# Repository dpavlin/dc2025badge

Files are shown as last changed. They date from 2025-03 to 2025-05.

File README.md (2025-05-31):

# DORS/CLUC Conference badge 2025

Conference page with badge instructions: [https://www.dorscluc.org/badge](https://www.dorscluc.org/badge/)

Build log: [https://hyperglitch.com/articles/dc2025-badge](https://hyperglitch.com/articles/dc2025-badge)

- `/hardware` - KiCad files for the badge
- `/firmware` - firmware for the badge
- `/3D` - 3D models for the stand, tag and programming jig
- `/notification_handler.py` - Python script for displaying the notifications and clock on the badge (in notifier mode)

----------------------------------------

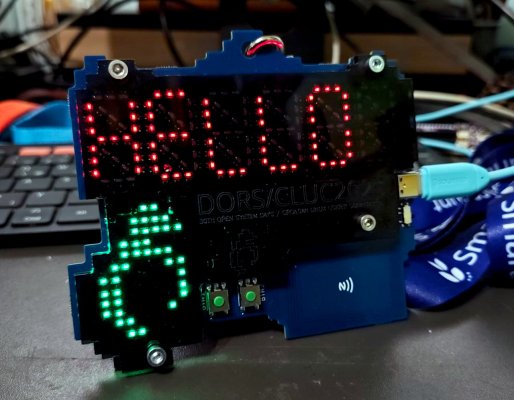
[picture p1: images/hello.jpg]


This year’s badge has a number of functionalities, to be used both during and after the conference. During the conference the display can show your name (or any other text) and you also use it for quests. After the conference it can be used as a handy desktop notifier or a clock. And, of course, there’s a game available on it (not really Doom but it’s fast paced and action packed).

The badge contains a six character 9-segment display, logo shaped LED matrix, a NFC reader/writer, two buttons and a USB connection.

## How to set my own text?

The badge has six character alphanumeric display. It can show messages of up to 30 characters.

To set your custom text, hold the BTN1 for about three to five seconds until the badge switches to configuration mode. In that mode the BTN1 will move the cursor position while BTN2 will change the character under the cursor (hold it for fast character listing). To delete a character, select a space symbol (after number 9). To save the text hold the BTN1 again for three to five seconds until OK appears on screen.

## Quests? You said quests?

Yes! One is treasure hunt and another is badge hunt.

On the conference site there are nine hidden tags and your quest is to “collect” them all (tap them with your badge, please don’t physically take them). Each hidden tag will light up part of the logo on the badge. The first person who gets all of them will get a small reward.

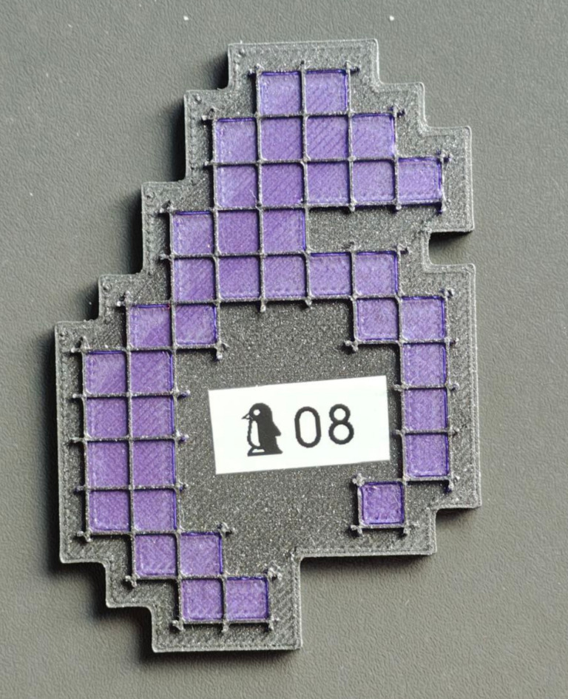
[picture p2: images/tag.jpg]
An example of a hidden tag


Just like the last year’s badge which motivated attendants to interact with each other, this year’s badge also has an “interaction counter”. Put the antennas on two badges next to each other for a couple of seconds (it’s best to hold them both upwards and put antennas one over another so both screens could be seen) until both of them show the “NEW BADGE FOUND” text and they will exchange their details, incrementing the badge counter. NOTE: due to the power saving feature this might need to be repeated multiple times.

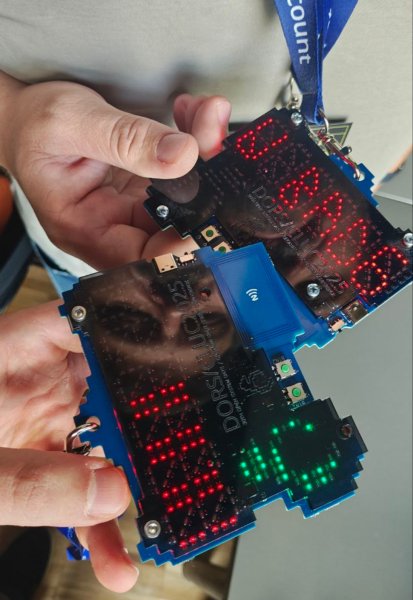
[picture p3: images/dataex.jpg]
How to hold badges for data exchange


To check the current status of both quests press the BTN2 once or twice.

Note: in order to preserve the battery life, the NFC reader is in power save mode and it will activate when it detects a moving metal object nearby. Because of that sometimes it will be necessary to try the action (tapping the hidden tag or another badge) a couple of times.

## There are other modes?

I’m glad you asked. Yes, there are other modes on the badge:

- Conference mode scrolling text with quests)
- Clock (not really precise, needs configuration)
- Notifier (“passthrough” mode allowing you to set the screen over USB so it can be used as a desktop notifier)
- Game (a game!)
- Test (hardware test used during production)

To change the mode press and hold both buttons while powering on the badge. After a couple of seconds MODE will appear on screen. Use buttons to select the mode you like to try and press and hold both buttons for three to five seconds to confirm the selection.

## Configuration

When the badge is not in the notifier mode, some settings can be configured using the configuration menu available over USB connection. Connect the badge to computer (it probably won’t work on smartphone) and a new serial port will appear (/dev/ttyACM* on Linux, COM* on Windows). Connect to it either using some terminal program (miniterm, putty, screen, …) or even a web client such as the one available at https://www.anticyclone-systems.co.uk/aslwebterm.php (a Chromium based browser needs to be used as Firefox doesn’t support WebSerial). Make sure that Enter is set as CR+LF, click Connect and select your badge. Press Enter to redraw the menu. In case the Enter doesn’t work, try Ctrl+J.

## Notifier mode

When in notifier mode the serial terminal isn’t used for configuration but for the control. Each command must end ith a newline. Here are the commands:

- `S<some text>` will display that text on screen (for example “`Sshow this`”)
- `G<char_idx><segment_idx><1|0>` will control a specified character segment. `<char_idx>` is character index (0-5), `<segment_idx>` is the index of the segment (0-8) and `1|0` controls whether to turn the segment on or off. For example “`G161`” will turn on the middle horizontal segment on second character.
- `L<led_idx><1|0>` will turn the specified LED in the logo on or off. `<led_idx>` is in the range 00-39 (with leading zero). For example “`L021`” will turn on the led with index 2.
- `C` will clear the screen and LED matrix.
- `B<brightness>` will set the brightness where the `<brightness>` is in the rangge 00-99 (with leading zero). For example “`B05`” will set the brightness to 5%.

## License

ST middlewares and libraries are licensed under ST SLA0044 license. Shell menu is licensed under GPLv3. The rest of the code is licensed under MIT license.

The badge is designed by Igor Brkić from [https://hyperglitch.com](https://hyperglitch.com).

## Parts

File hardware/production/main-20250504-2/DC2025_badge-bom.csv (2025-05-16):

Comment | Designator | Footprint | LCSC
TVS3V | D1,D207,D208,D209,D210,D211,D213,D214 | Diode_SMD:D_SOD-323 | C502526
1uF | C4,C10,C23,C41,C42,C43,C44 | Capacitor_SMD:C_0603_1608Metric | C59302
100k | R1,R3,R4,R8,R11,R178 | Resistor_SMD:R_0402_1005Metric | C25741
SMF5.0A | D203,D204,D205,D206 | Diode_SMD:D_SMF | C19077497
Cover nut | H3,H4,H5,H6 | SMTSO:SMTSO3025CTJ | C2916365
100nF | C1,C5,C6,C7,C9,C11,C15,C16,C17,C18,C19,C20,C21,C22,C29,C45 | Capacitor_SMD:C_0402_1005Metric | C307331
SKHMQLE010 | S2,S3 | SW_SKHMQLE010:SW_SKHMQLE010 | C139767
22nF | C3 | Capacitor_SMD:C_0402_1005Metric | C1532
USB_C_Receptacle_USB2.0_16P | J1 | Connector_USB:USB_C_Receptacle_GCT_USB4105-xx-A_16P_TopMnt_Horizontal | C165948
TPS3808DBV | U1 | Package_TO_SOT_SMD:SOT-23-6 | C19653
AO3401A | Q1 | Package_TO_SOT_SMD:SOT-23 | C15127
5.1k | R6,R7,R9,R10 | Resistor_SMD:R_0402_1005Metric | C25905
SSSS811101 | S1 | SW_SSSS811101:SW_SSSS811101 | C109335
STM32L073RBT6 | U2 | Package_QFP:LQFP-64_10x10mm_P0.5mm | C2917159
XC6206P332MR | U5,U6 | Package_TO_SOT_SMD:SOT-23-3 | C5446
10k | R5,R177,R179,R180,R181,R182,R183 | Resistor_SMD:R_0402_1005Metric | C25744
MBR0530 | D212 | Diode_SMD:D_SOD-123 | C475718
10uF | C2,C8,C28 | Capacitor_SMD:C_0603_1608Metric | C237435
47R | R12,R13,R14,R15,R16,R17,R18,R19,R20,R21,R22,R23,R24,R25,R26,R27,R28,R29,R30,R31,R32,R33,R34,R35,R36,R37,R38,R39,R40,R41,R42,R43,R44,R45,R46,R47,R48,R49,R50,R51,R52,R53,R54,R55,R56,R57,R58,R59,R60,R61,R62,R63,R64,R65,R66,R67,R68,R69,R70,R71,R72,R73,R74,R75,R76,R77,R78,R79,R80,R81,R82,R83,R84,R85,R86,R87,R88,R89,R90,R91,R92,R93,R94,R95,R96,R97,R98,R99,R100,R101,R102,R103,R104,R105,R106,R107,R108,R109,R110,R111 | Resistor_SMD:R_0402_1005Metric | C25118
47R | R112,R113,R114,R115,R116,R117,R118,R119,R120,R121,R122,R123,R124,R125,R126,R127,R128,R129,R130,R131,R132,R133,R134,R135,R136,R137,R138,R139,R140,R141,R142,R143,R144,R145,R146,R147,R148,R149,R150,R151,R152,R153,R154,R155,R156,R157,R158,R159,R160,R161,R162,R163,R164,R165,R166,R167,R168,R169,R170,R171,R172,R173 | Resistor_SMD:R_0402_1005Metric | C25118
RED | D41,D42,D43,D44,D45,D46,D47,D48,D49,D50,D51,D52,D53,D54,D55,D56,D57,D58,D59,D60,D61,D62,D63,D64,D65,D66,D67,D68,D69,D70,D71,D72,D73,D74,D75,D76,D77,D78,D79,D80,D81,D82,D83,D84,D85,D86,D87,D88,D89,D90,D91,D92,D93,D94,D95,D96,D97,D98,D99,D100,D101,D102,D103,D104,D105,D106,D107,D108,D109,D110,D111,D112,D113,D114,D115,D116,D117,D118,D119,D120,D121,D122,D123,D124,D125,D126,D127,D128,D129,D130,D131,D132,D133,D134,D135,D136,D137,D138,D139,D140 | LED_SMD:LED_0603_1608Metric | C965799
RED | D141,D142,D143,D144,D145,D146,D147,D148,D149,D150,D151,D152,D153,D154,D155,D156,D157,D158,D159,D160,D161,D162,D163,D164,D165,D166,D167,D168,D169,D170,D171,D172,D173,D174,D175,D176,D177,D178,D179,D180,D181,D182,D183,D184,D185,D186,D187,D188,D189,D190,D191,D192,D193,D194,D195,D196,D197,D198,D199,D200,D201,D202 | LED_SMD:LED_0603_1608Metric | C965799
GRN | D2,D3,D4,D5,D6,D7,D8,D9,D10,D11,D12,D13,D14,D15,D16,D17,D18,D19,D20,D21,D22,D23,D24,D25,D26,D27,D28,D29,D30,D31,D32,D33,D34,D35,D36,D37,D38,D39,D40 | LED_SMD:LED_0603_1608Metric | C965804
IS31FL3731-QF | U3 | Package_DFN_QFN:QFN-28-1EP_4x4mm_P0.4mm_EP2.3x2.3mm | C191206
2.2uF | C14,C24,C25,C26,C27,C34 | Capacitor_SMD:C_0603_1608Metric | C23630
150pF | C36,C37,C39,C40 | Capacitor_SMD:C_0402_1005Metric | C1527
ST25R3916-AQWT | U4 | Package_DFN_QFN:UFQFPN-32-1EP_5x5mm_P0.5mm_EP3.5x3.5mm | C2908147
220pF | C30,C33 | Capacitor_SMD:C_0402_1005Metric | C1530
270nH | L1,L2 | Inductor_SMD:L_0402_1005Metric_Pad0.77x0.64mm_HandSolder | C907954
2R | R175,R176 | Resistor_SMD:R_0402_1005Metric | C170397
10pF | C12,C13,C35,C38 | Capacitor_SMD:C_0402_1005Metric | C32949
680pF | C31,C32 | Capacitor_SMD:C_0402_1005Metric | C1541
27.12MHz | Y1 | Crystal:Crystal_SMD_3225-4Pin_3.2x2.5mm | C29975

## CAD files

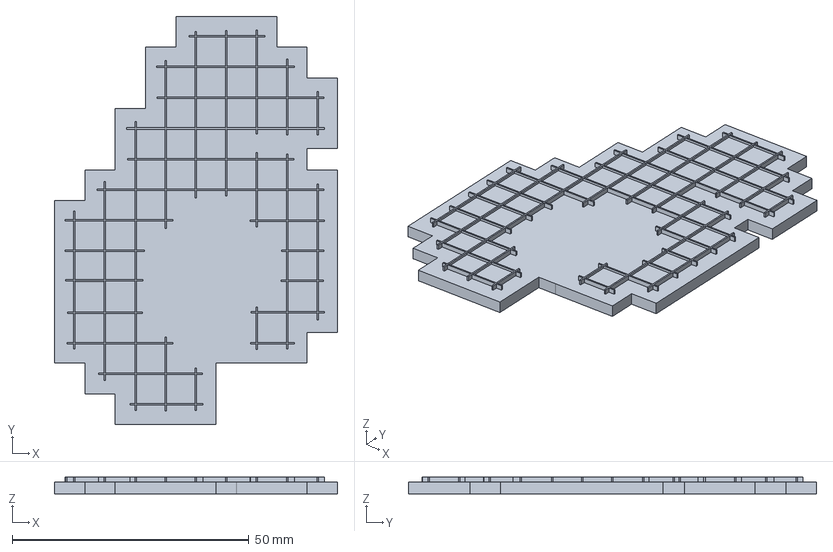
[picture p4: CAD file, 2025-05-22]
3D/treasure_hunt_tag.FCStd
59.9 x 86.2 x 3.50 mm

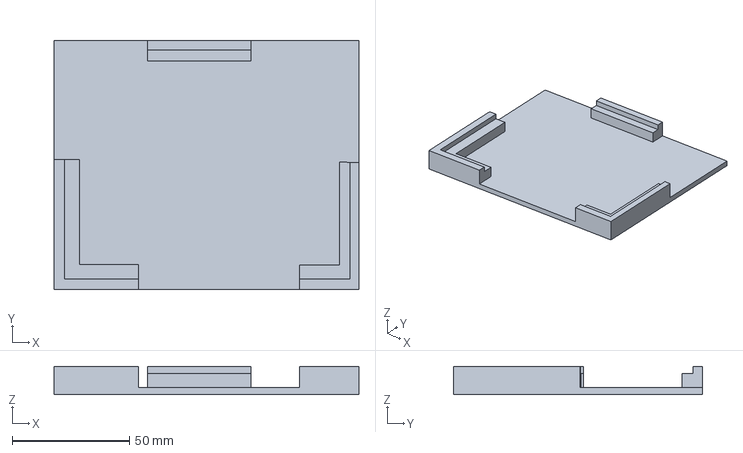
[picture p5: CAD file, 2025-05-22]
3D/programming_jig.FCStd
130.3 x 106.5 x 12.0 mm

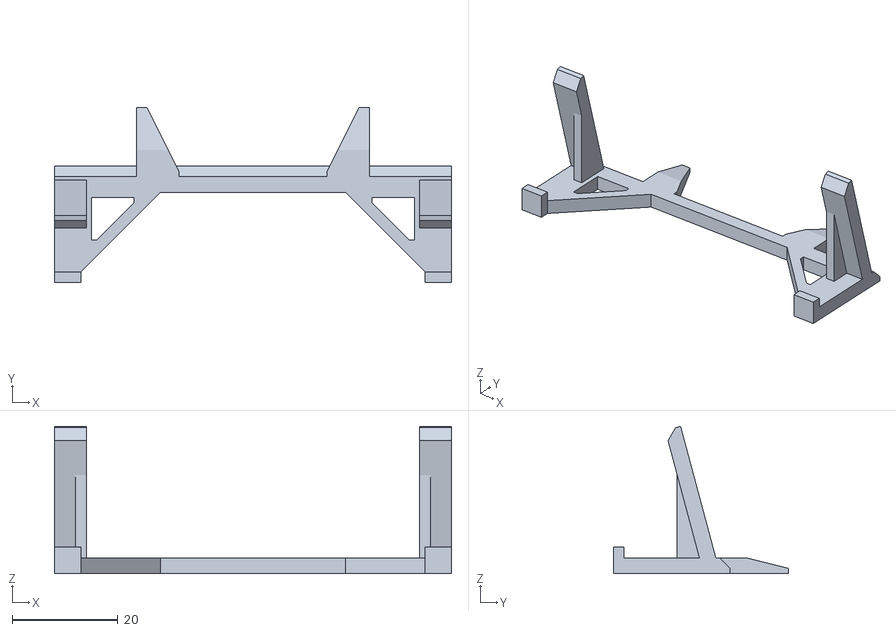
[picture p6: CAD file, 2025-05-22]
3D/badge_stand-Cut.stl
75.0 x 33.0 x 27.8

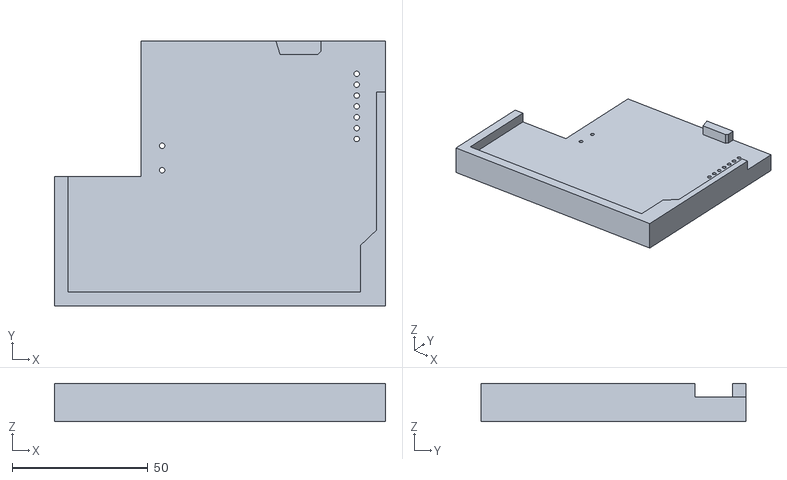
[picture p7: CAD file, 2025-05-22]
3D/programming_jig-holder.stl
121.9 x 97.6 x 14.0

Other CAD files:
3D/programming_jig-Body.stl
3D/treasure_hunt_tag-Cut.stl
3D/badge_stand.FCStd

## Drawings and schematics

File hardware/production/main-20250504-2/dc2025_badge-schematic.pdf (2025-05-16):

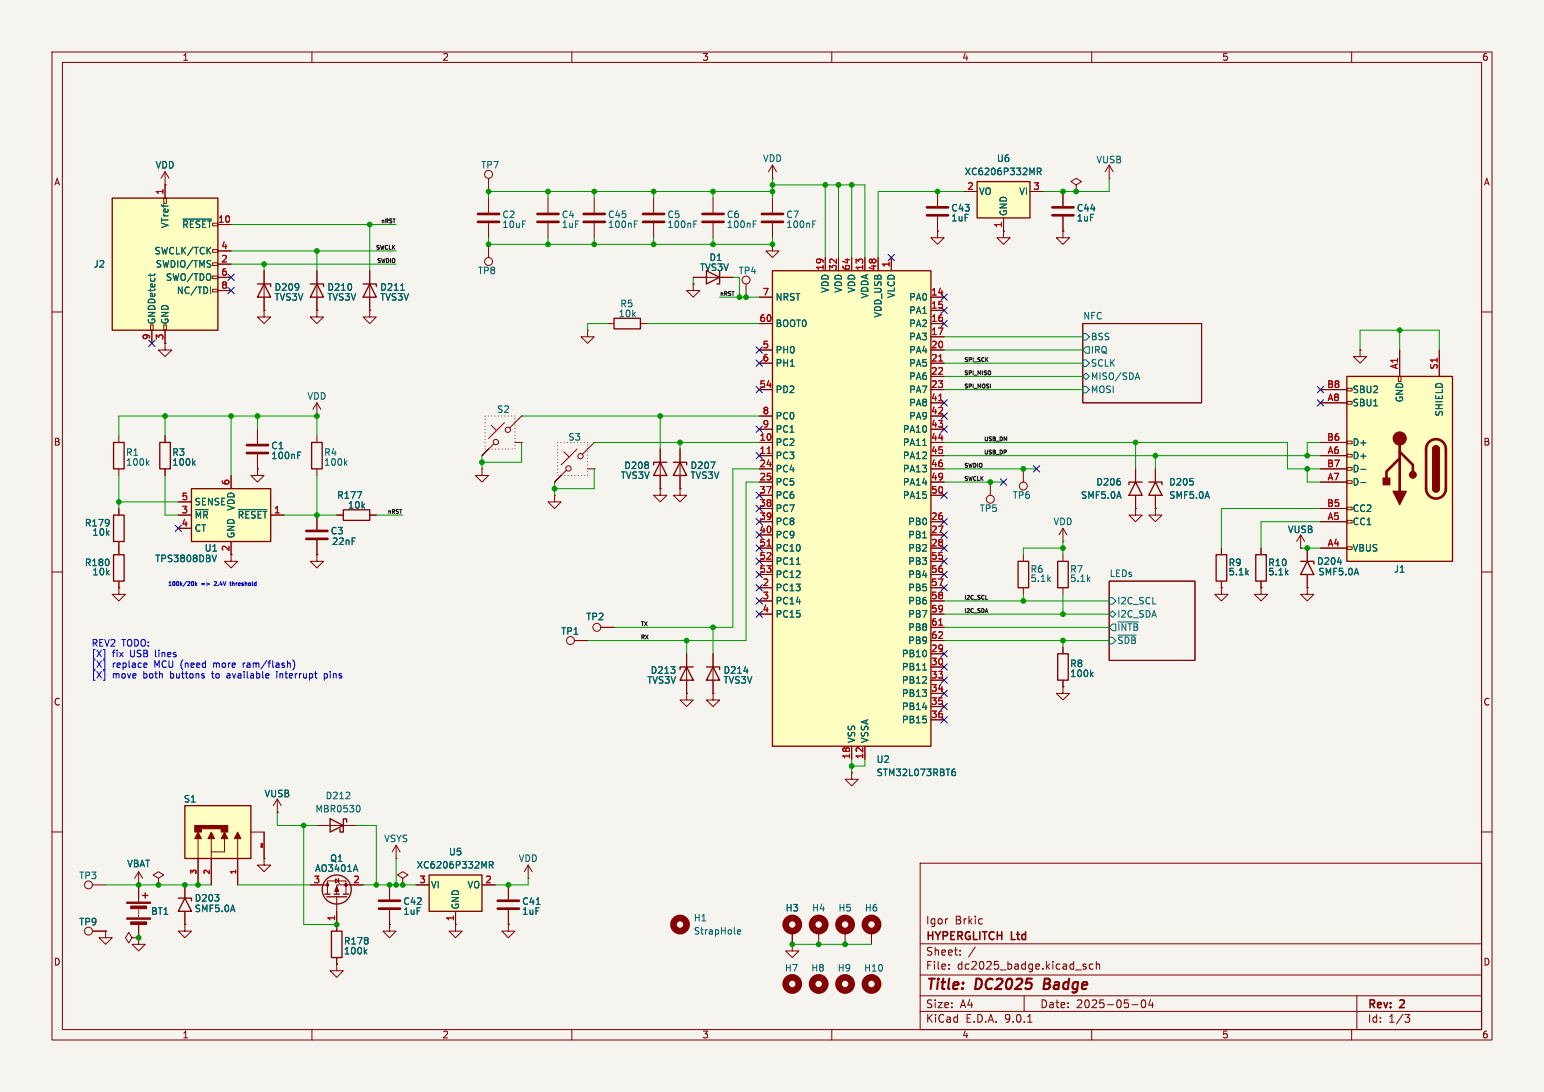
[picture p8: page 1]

3 ~{RESET}10 SWCLK/TCK 4 SWDIO/TMS 2 SWO/TDO 6 NC/TDI 8

IRQ MISO/SDA MOSI SCLK NFC
~{SDB} LEDs BSS

[X] fix USB lines
[X] replace MCU (need more ram/flash)

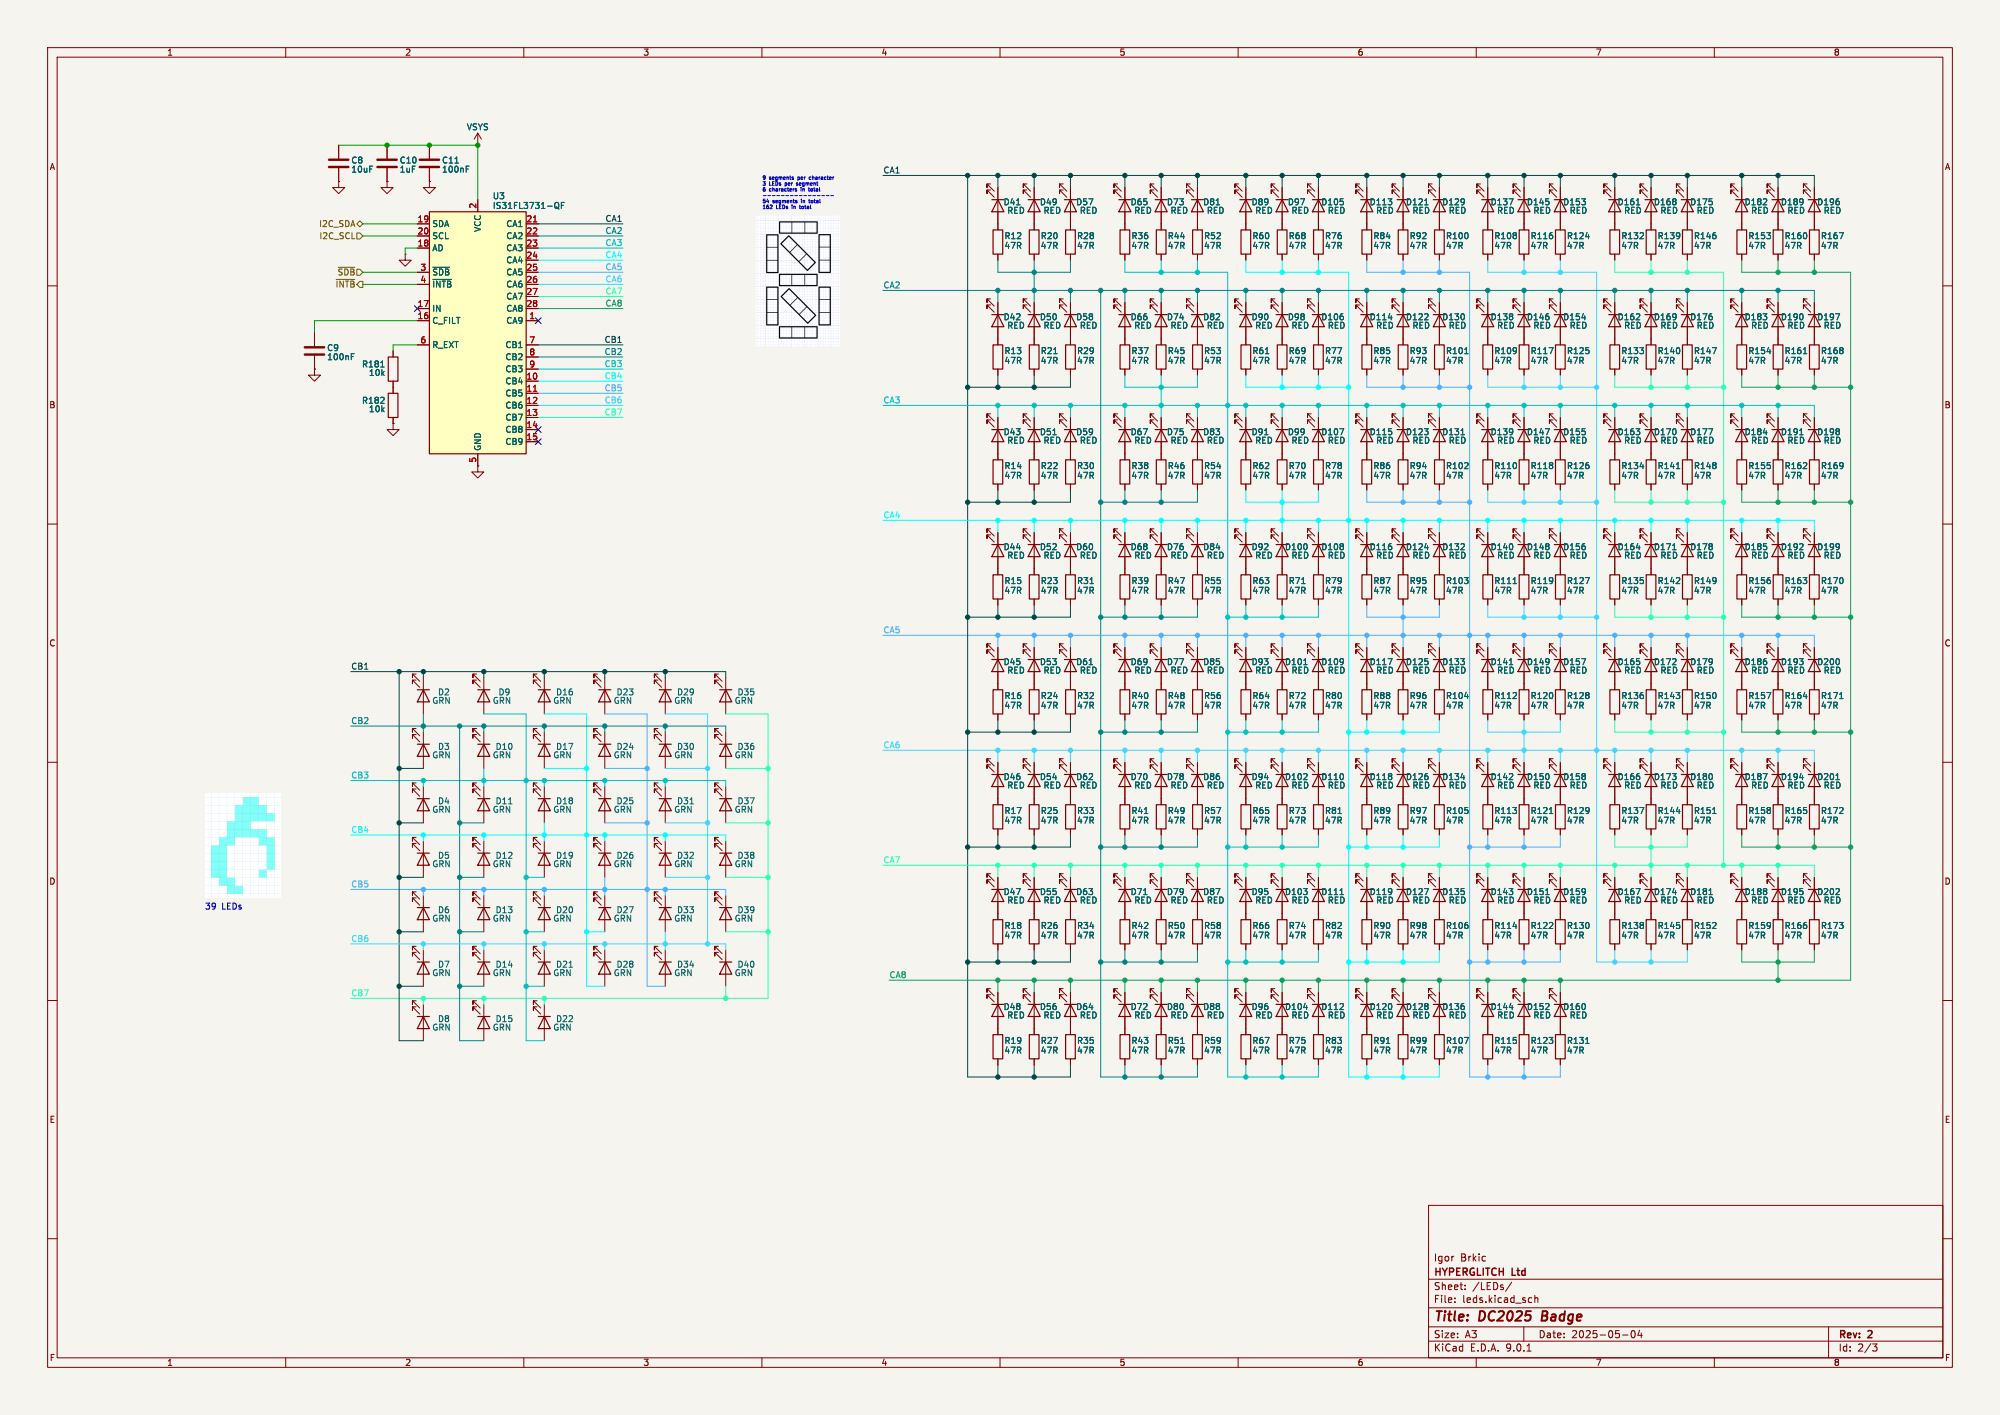
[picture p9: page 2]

IS31FL3731-QF SDA 19 SCL 20 AD 18 ~{SDB} 3 ~{INTB} 4

5 CA1 21 CA2 22 CA3 23 CA4 24 CA5 25 CA6 26 CA7 27 CA8 28 CA9 1 CB1 7 CB2 8 CB3 9 CB4 10 CB5 11 CB6 12 CB7 13 CB8 14 CB9 15 D57 RED
SDA 19 SCL 20 AD 18 ~{SDB} 3 ~{INTB} 4

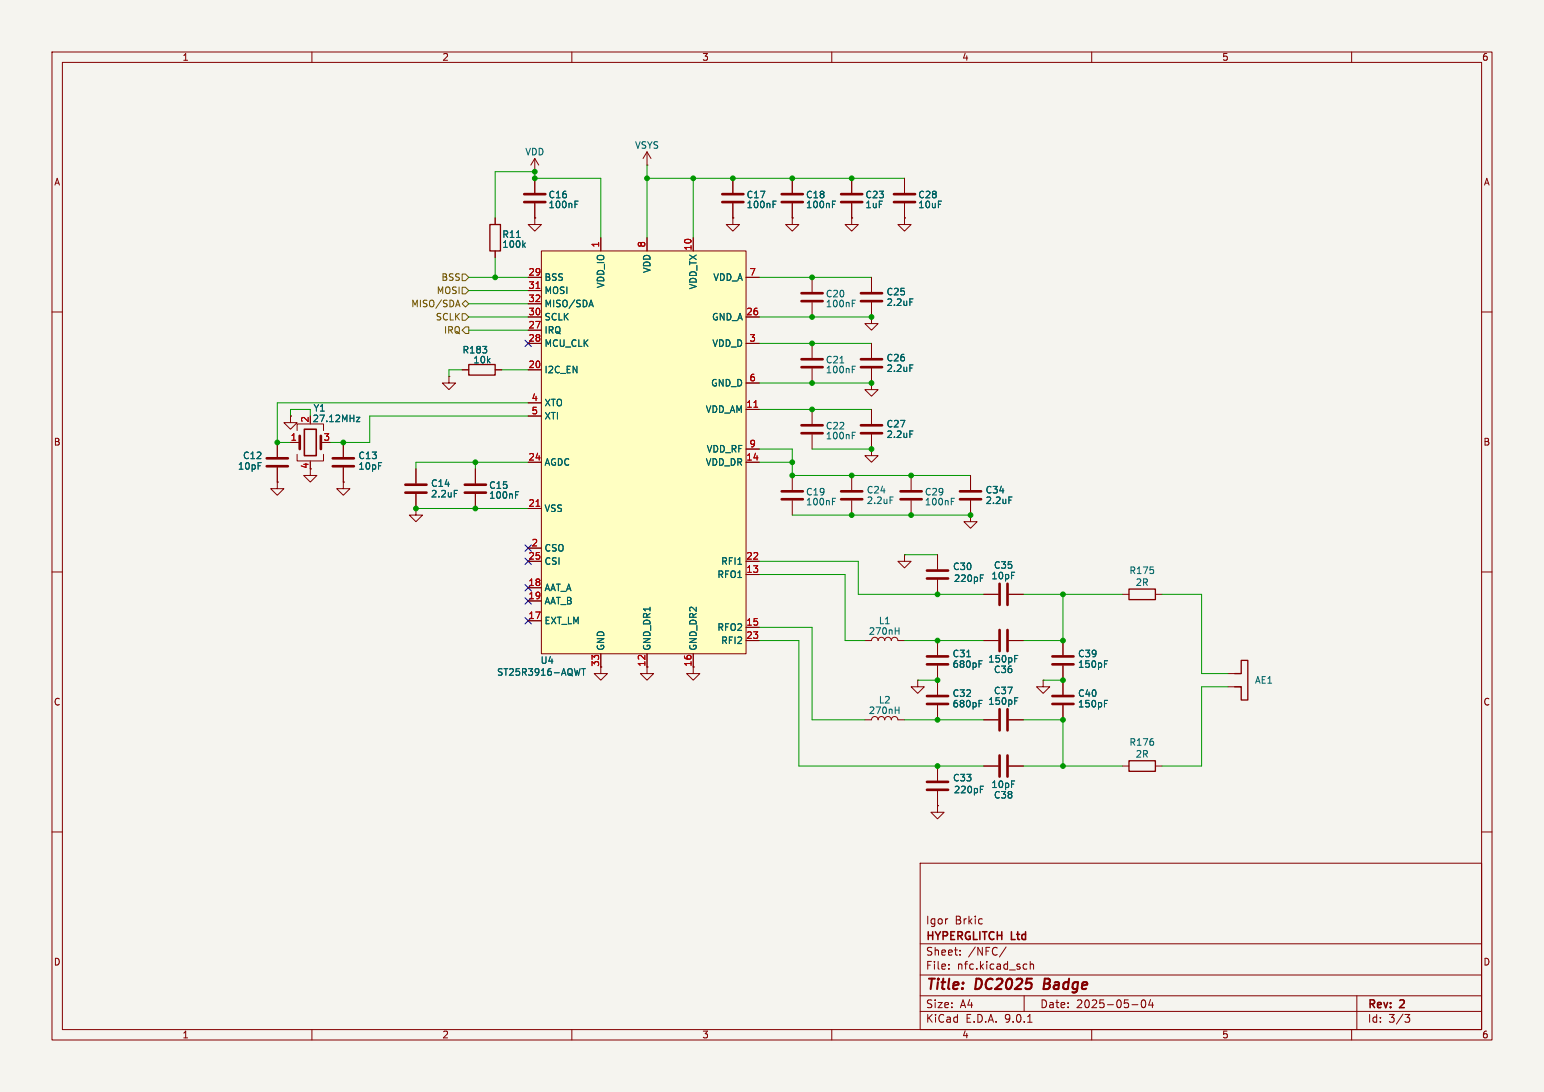
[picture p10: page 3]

BSS
IRQ MOSI MISO/SDA

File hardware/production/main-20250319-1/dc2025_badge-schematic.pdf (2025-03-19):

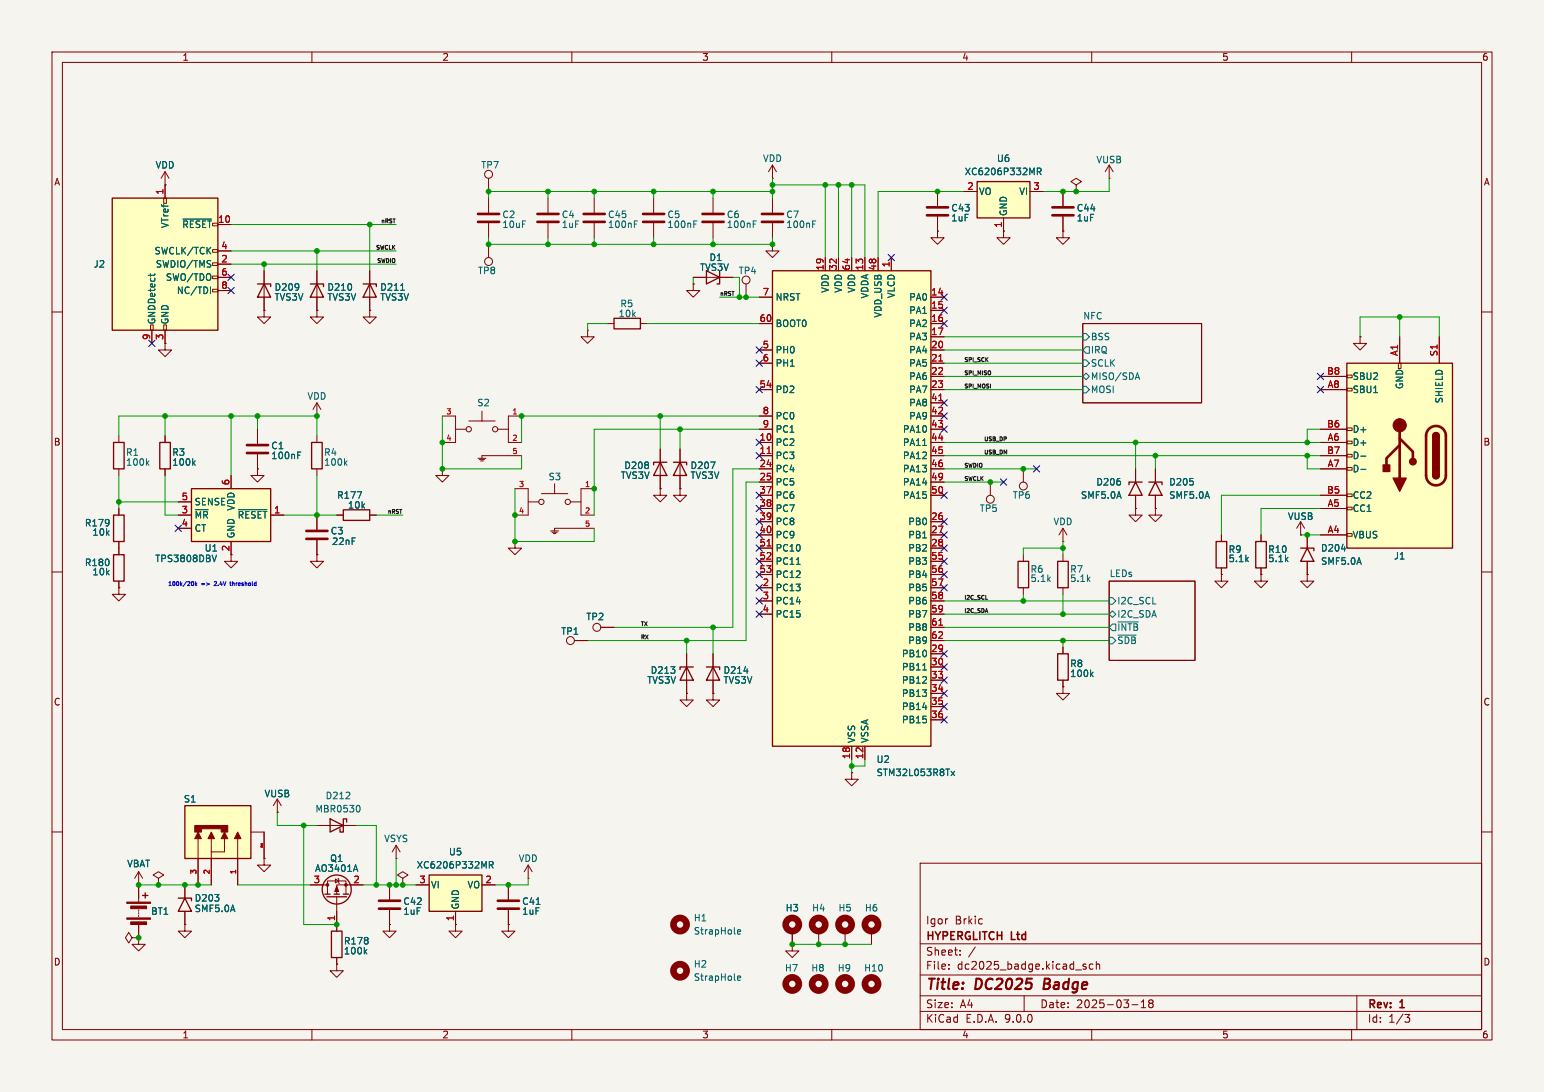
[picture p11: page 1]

3 ~{RESET}10 SWCLK/TCK 4 SWDIO/TMS 2 SWO/TDO 6 NC/TDI 8 VDD

3 ~{RESET}10 SWCLK/TCK 4 SWDIO/TMS 2 SWO/TDO 6 NC/TDI 8

IRQ MISO/SDA MOSI SCLK NFC
SPI_SCKUSB_DP USB_DM

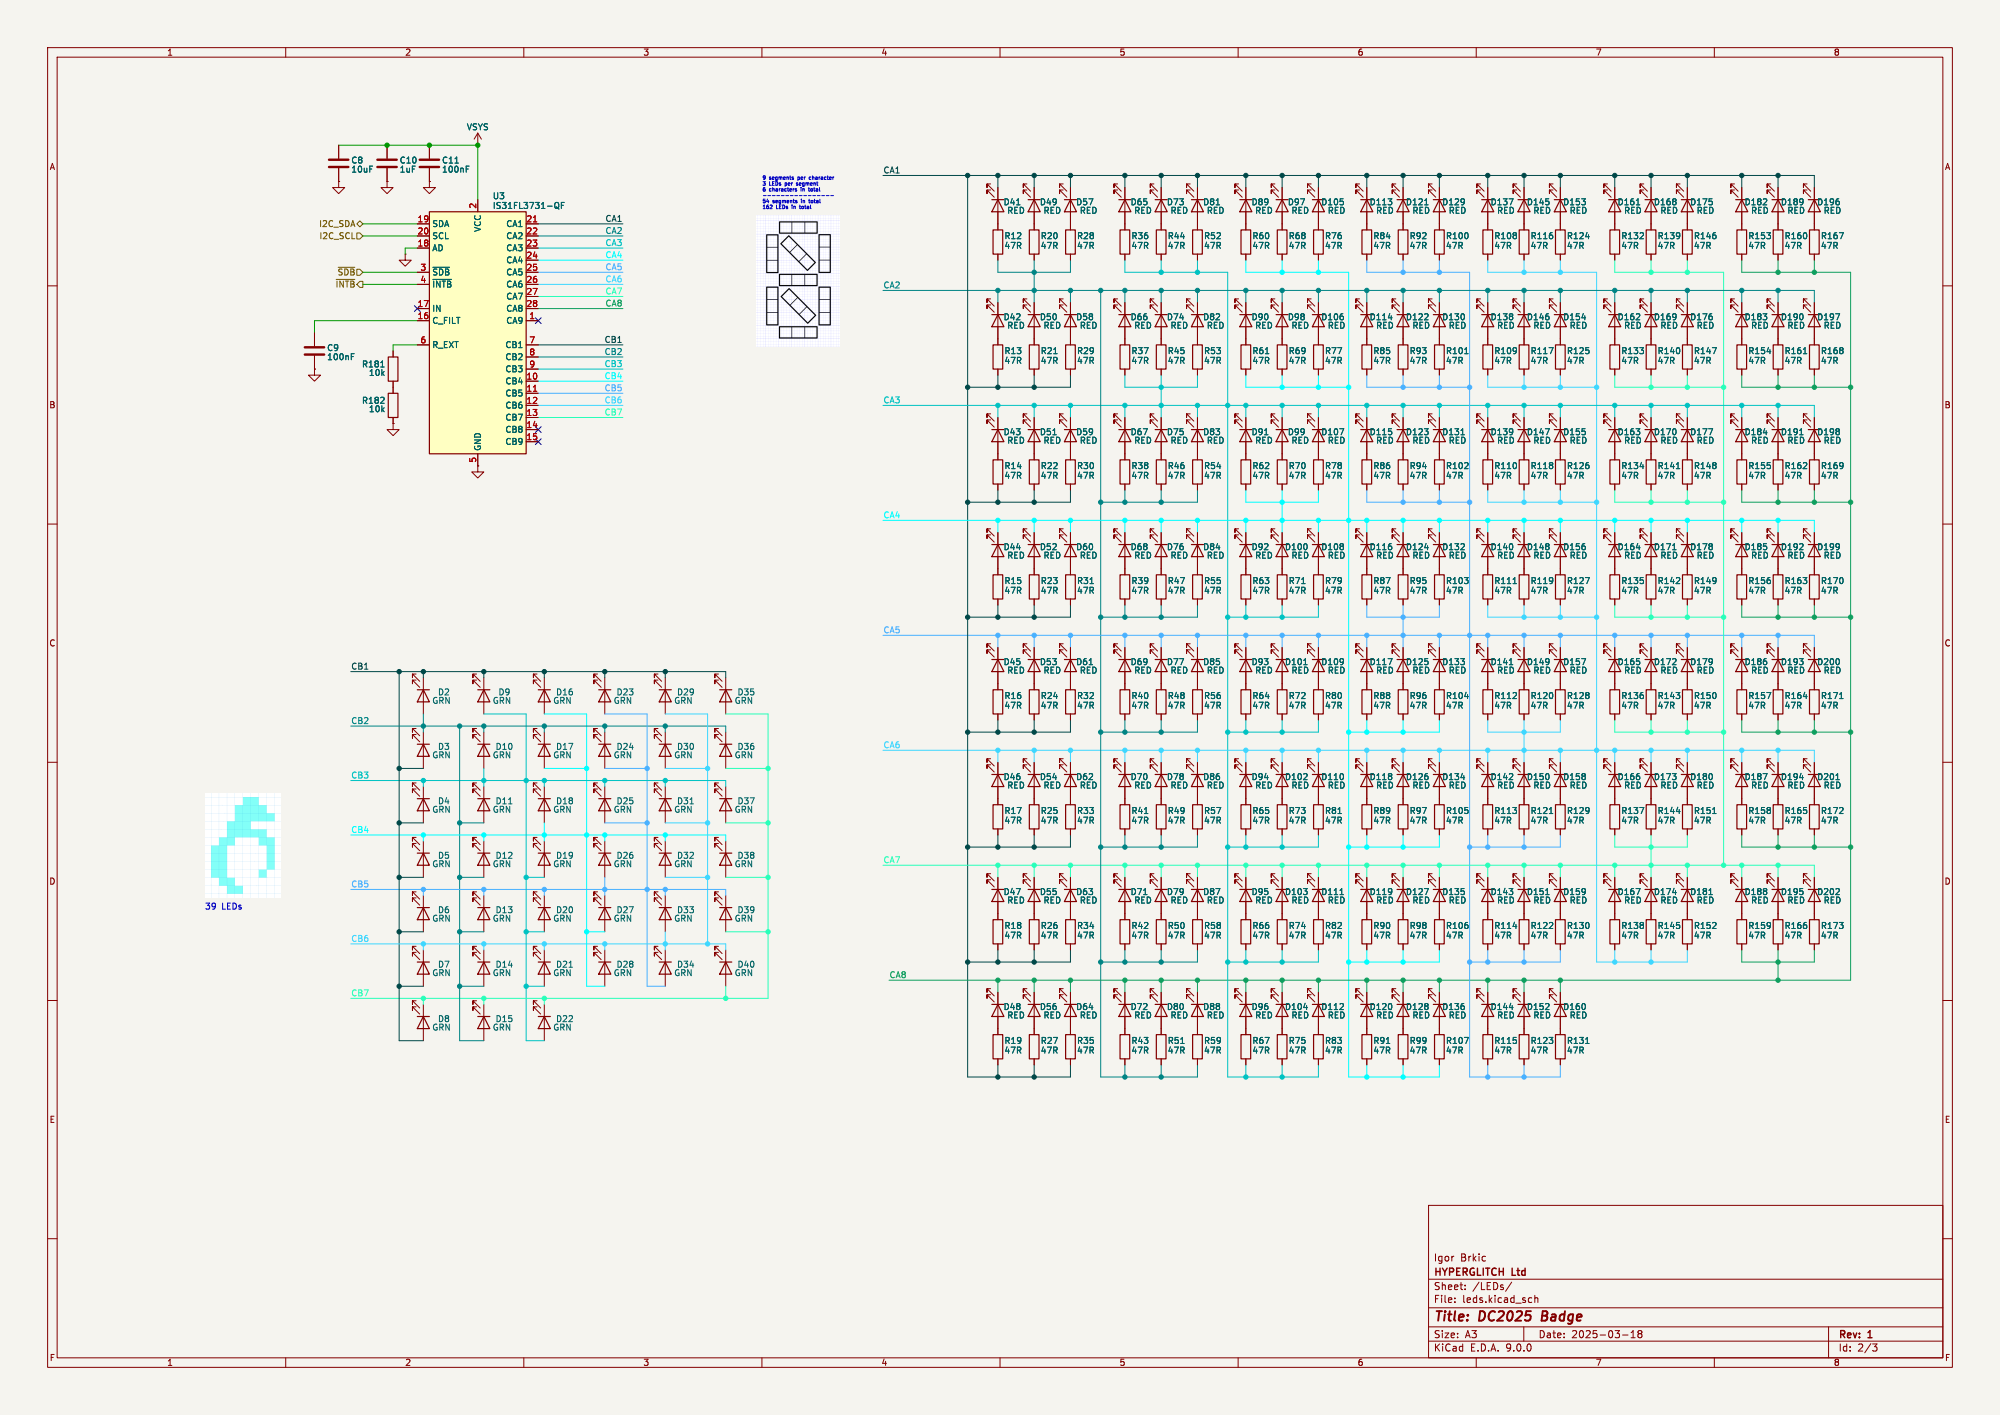
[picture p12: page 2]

IS31FL3731-QF SDA 19 SCL 20 AD 18 ~{SDB} 3 ~{INTB} 4

5 CA1 21 CA2 22 CA3 23 CA4 24 CA5 25 CA6 26 CA7 27 CA8 28 CA9 1 CB1 7 CB2 8 CB3 9 CB4 10 CB5 11 CB6 12 CB7 13 CB8 14 CB9 15 D57 RED
SDA 19 SCL 20 AD 18 ~{SDB} 3 ~{INTB} 4

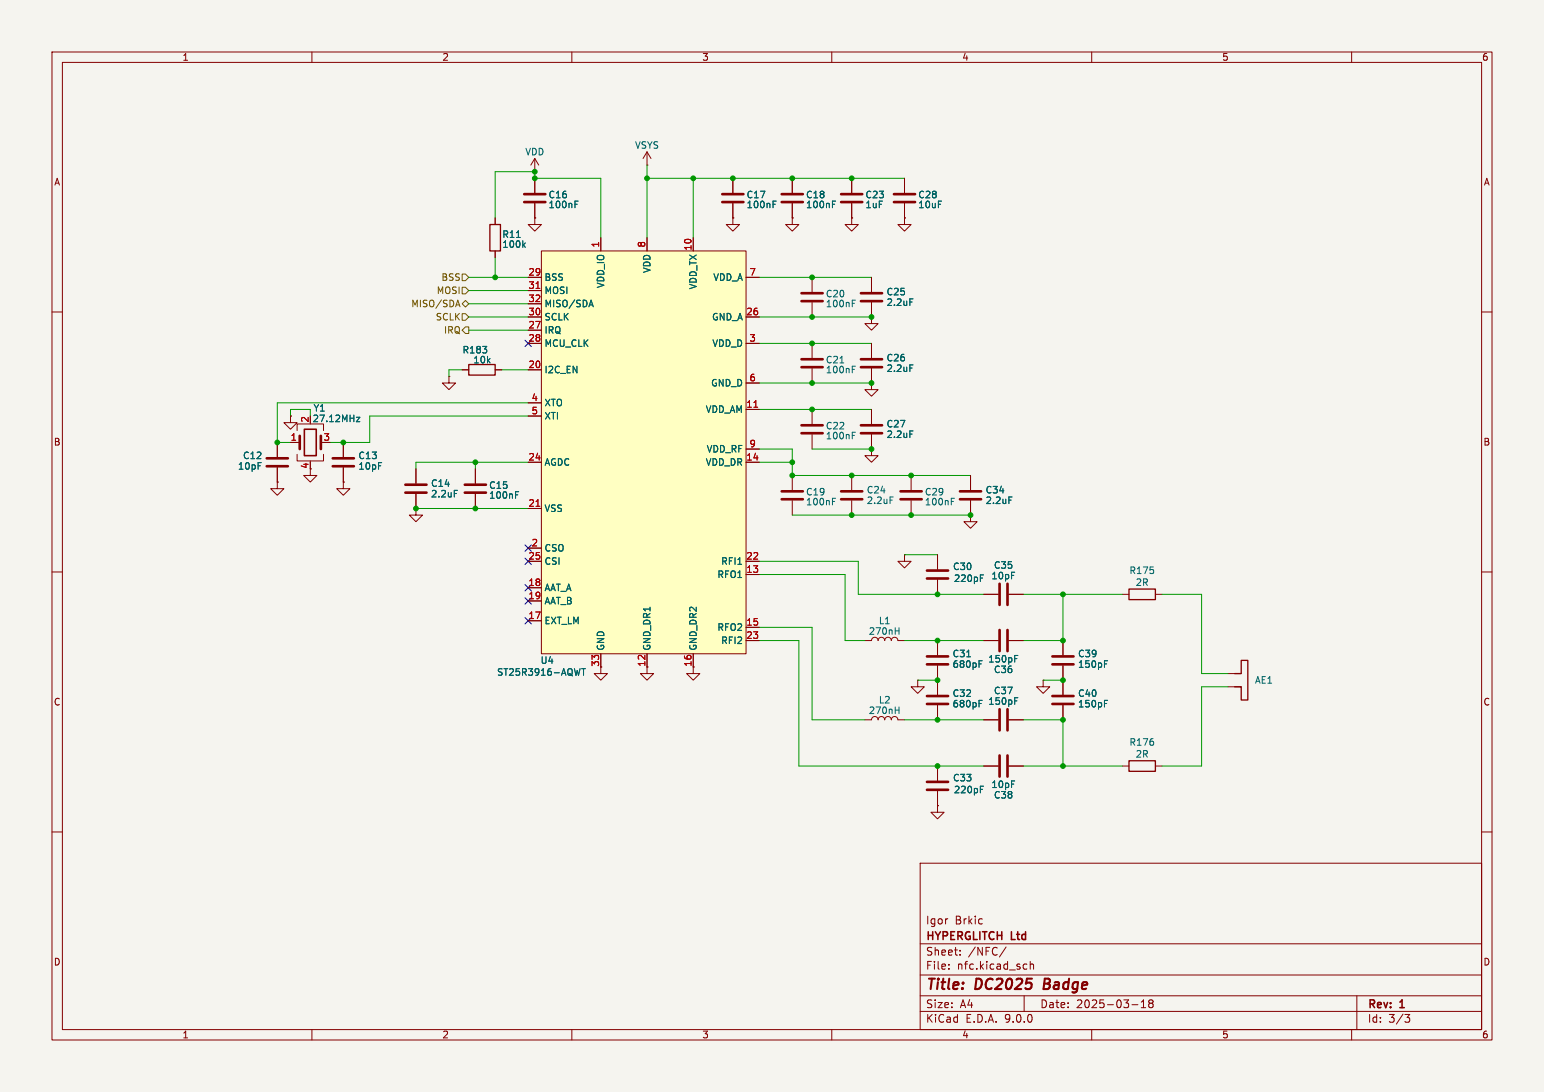
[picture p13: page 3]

BSS
IRQ MOSI MISO/SDA

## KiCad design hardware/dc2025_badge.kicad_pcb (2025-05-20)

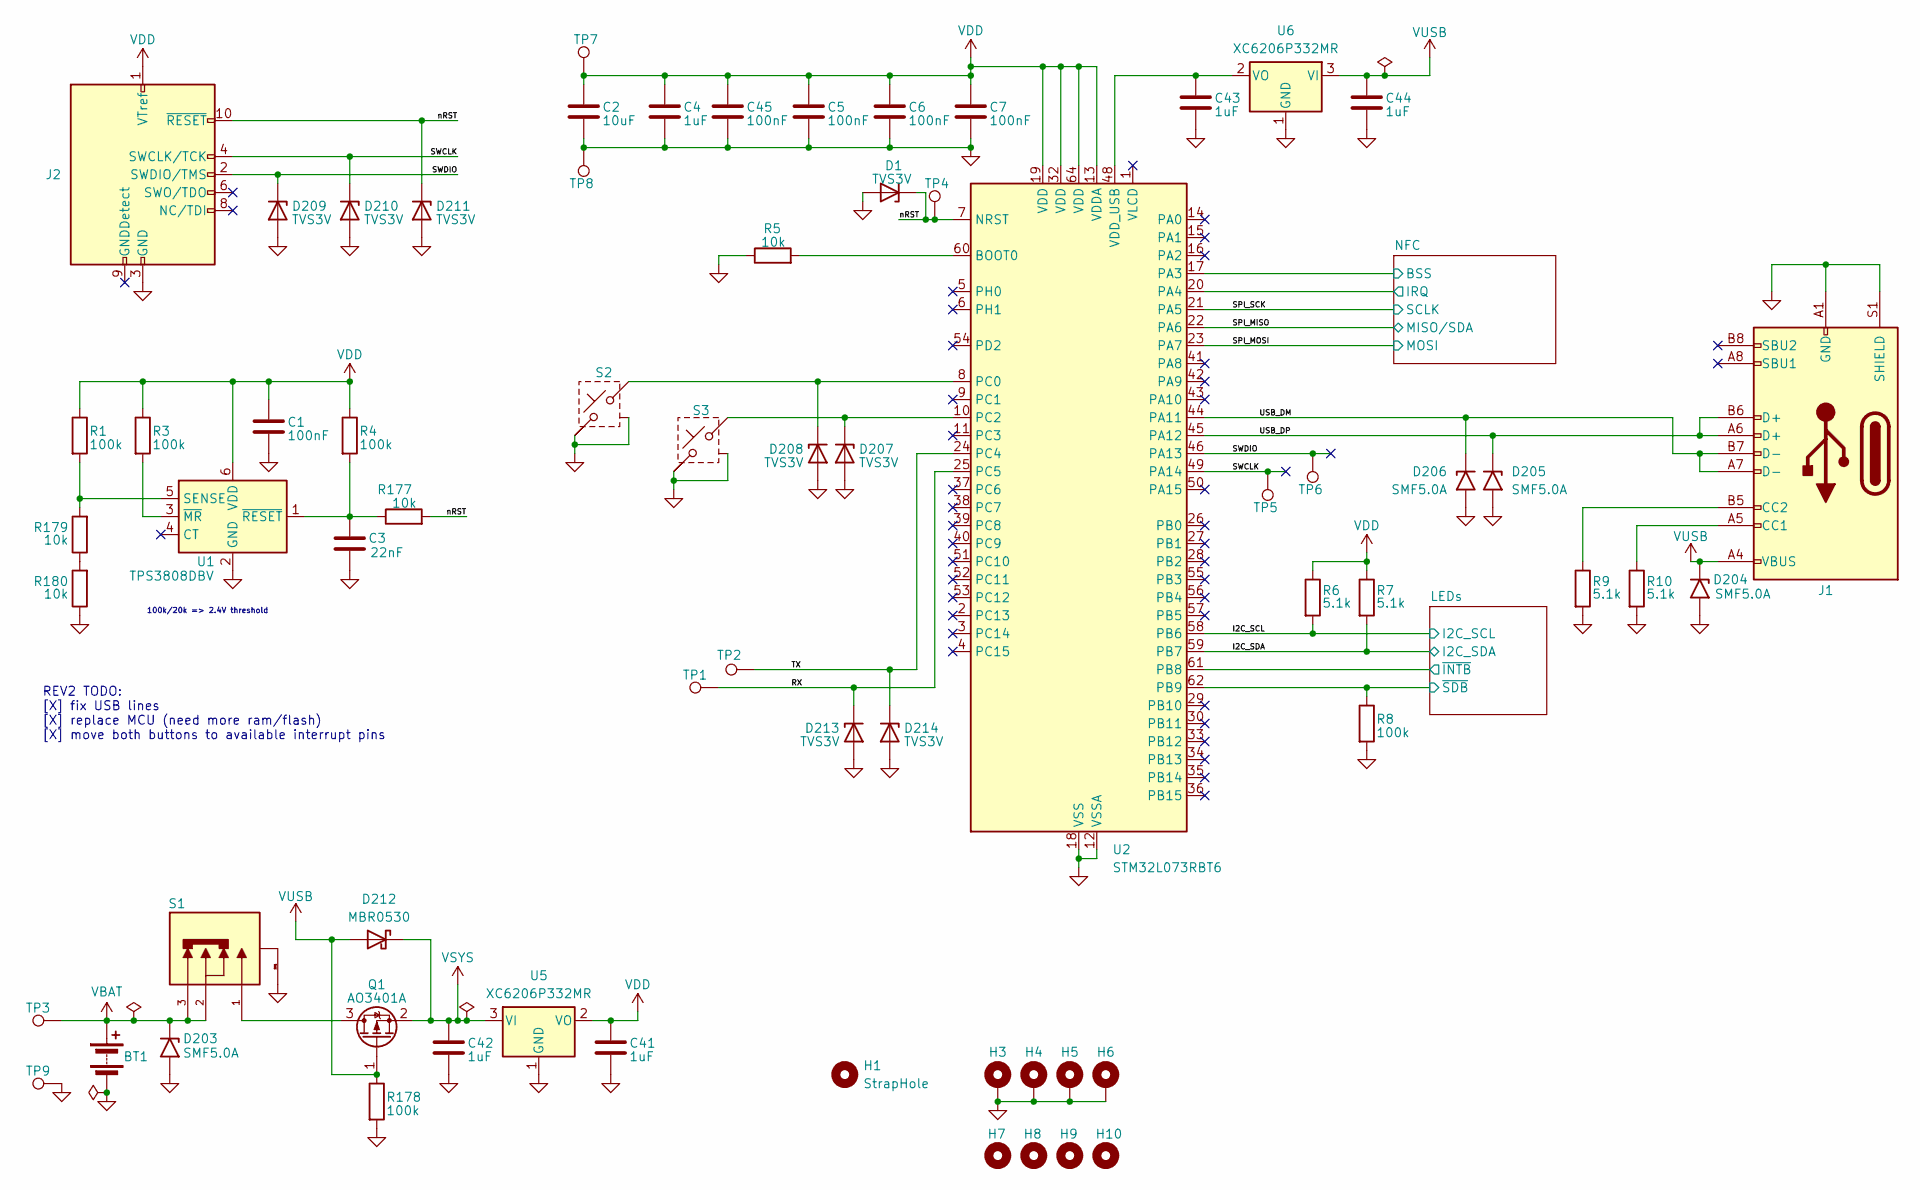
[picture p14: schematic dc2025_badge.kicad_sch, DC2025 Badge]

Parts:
BT1: Battery; keystone_2464
C1, C5, C6, C7, C45: 100nF; C_0402_1005Metric; MPN CL05B104KB54PNC; JLCPCB# C307331
C2: 10uF; C_0603_1608Metric; MPN GRM188Z71A106MA73D; JLCPCB# C237435
C3: 22nF; C_0402_1005Metric; MPN 0402B223K500NT; JLCPCB# C1532
C4, C41, C42, C43, C44: 1uF; C_0603_1608Metric; MPN 0603B105K250NT; JLCPCB# C59302
D1, D207, D208, D209, D210, D211, D213, D214: TVS3V; D_SOD-323; MPN SD03; JLCPCB# C502526
D203, D204, D205, D206: SMF5.0A; D_SMF; MPN SMF5.0A; JLCPCB# C19077497
D212: MBR0530; D_SOD-123; MPN MBR0530; JLCPCB# C475718
H1: StrapHole; MountingHole_5mm
H3, H4, H5, H6: Cover nut; SMTSO3025CTJ; MPN C2916365; JLCPCB# C2916365
H7, H8, H9, H10: CoverMountingHole; MountingHole_3.2mm_M3_DIN965
J1: USB_C_Receptacle_USB2.0_16P; USB_C_Receptacle_GCT_USB4105-xx-A_16P_TopMnt_Horizontal; MPN TYPE-C-31-M-12; JLCPCB# C165948
J2: Conn_ARM_JTAG_SWD_10; Tag-Connect_TC2050-IDC-NL_2x05_P1.27mm_Vertical_with_bottom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
Q1: AO3401A; SOT-23; MPN AO3401A; JLCPCB# C15127
R1, R3, R4, R8, R178: 100k; R_0402_1005Metric; MPN 0402WGF1003TCE; JLCPCB# C25741
R5, R177, R179, R180: 10k; R_0402_1005Metric; MPN 0402WGF1002TCE; JLCPCB# C25744
R6, R7, R9, R10: 5.1k; R_0402_1005Metric; MPN 0402WGF5101TCE; JLCPCB# C25905
S1: SSSS811101; SW_SSSS811101; MPN SSSS811101; JLCPCB# C109335
S2, S3: SKHMQLE010; SW_SKHMQLE010; MPN SKHMQLE010; JLCPCB# C139767
TP1, TP2, TP3, TP4, TP5, TP6, TP7, TP8, TP9: TestPoint; TestPoint_Pad_D2.0mm
U1: TPS3808DBV; SOT-23-6; MPN TPS3808G01DBVR; JLCPCB# C19653
U2: STM32L073RBT6; LQFP-64_10x10mm_P0.5mm; MPN STM32L073RBT6; JLCPCB# C2917159
U5, U6: XC6206P332MR; SOT-23-3; MPN XC6206P332MR-G; JLCPCB# C5446

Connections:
/I2C_SCL: R6.2, U2.58 (PB6); also elsewhere on the board
/I2C_SDA: R7.2, U2.59 (PB7); also elsewhere on the board
/LEDs/~INTB: U2.61 (PB8); also elsewhere on the board
/LEDs/~SDB: R8.1, U2.62 (PB9); also elsewhere on the board
/NFC/BSS: U2.17 (PA3); also elsewhere on the board
/NFC/IRQ: U2.20 (PA4); also elsewhere on the board
/RX: D213.1 (K), TP1.1, U2.25 (PC5)
/SPI_MISO: U2.22 (PA6); also elsewhere on the board
/SPI_MOSI: U2.23 (PA7); also elsewhere on the board
/SPI_SCK: U2.21 (PA5); also elsewhere on the board
/SWCLK: D210.1 (K), J2.4 (SWCLK/TCK), TP5.1, U2.49 (PA14)
/SWDIO: D209.1 (K), J2.2 (SWDIO/TMS), TP6.1, U2.46 (PA13)
/TX: D214.1 (K), TP2.1, U2.24 (PC4)
/USB_DM: D206.1 (A1), J1.A7 (D-), J1.B7 (D-), U2.44 (PA11)
/USB_DP: D205.1 (A1), J1.A6 (D+), J1.B6 (D+), U2.45 (PA12)
/nRST: D1.1 (K), D211.1 (K), J2.10 (~RESET), R177.2, TP4.1, U2.7 (NRST)
GND: BT1.2 (-), C1.2, C2.2, C3.2, C4.2, C5.2, C6.2, C7.2, C41.2, C42.2, C43.2, C44.2, C45.2, D1.2 (A), D203.2 (A2), D204.2 (A2), D205.2 (A2), D206.2 (A2), D207.2 (A), D208.2 (A), D209.2 (A), D210.2 (A), D211.2 (A), D213.2 (A), D214.2 (A), H3.1, H4.1, H5.1, H6.1, J1.A1 (GND), J1.A12 (GND), J1.B1 (GND), J1.B12 (GND), J1.S1 (SHIELD), J2.3 (GND), J2.5 (GND), R5.1, R8.2, R9.2, R10.2, R178.2, R180.1, S1.SH1, S1.SH2, S1.SH3, S1.SH4, S2.3, S2.4, S2.5, S3.3, S3.4, S3.5, TP8.1, TP9.1, U1.2 (GND), U2.12 (VSSA), U2.18 (VSS), U2.31 (VSS), U2.47 (VSS), U2.63 (VSS), U5.1 (GND), U6.1 (GND); also elsewhere on the board
unnamed: D207.1 (K), S3.1, S3.2, U2.10 (PC2)
unnamed: D208.1 (K), S2.1, S2.2, U2.8 (PC0)
unnamed: J1.A5 (CC1), R10.1
unnamed: J1.B5 (CC2), R9.1
unnamed: Q1.3 (D), S1.1
unnamed: R179.1, R180.2
unnamed: R1.2, R179.2, U1.5 (SENSE)
unnamed: R3.2, U1.3 (~MR)
unnamed: C3.1, R4.2, R177.1, U1.1 (~RESET)
unnamed: R5.2, U2.60 (BOOT0)
unnamed: C43.1, U2.48 (VDD_USB), U6.2 (VO)
VBAT: BT1.1 (+), D203.1 (A1), S1.2, S1.3, TP3.1
VDD: C1.1, C2.1, C4.1, C5.1, C6.1, C7.1, C41.1, C45.1, J2.1 (VTref), R1.1, R3.1, R4.1, R6.1, R7.1, TP7.1, U1.6 (VDD), U2.13 (VDDA), U2.19 (VDD), U2.32 (VDD), U2.64 (VDD), U5.2 (VO); also elsewhere on the board
VSYS: C42.1, D212.1 (K), Q1.2 (S), U5.3 (VI); also elsewhere on the board
VUSB: C44.1, D204.1 (A1), D212.2 (A), J1.A4 (VBUS), J1.A9 (VBUS), J1.B4 (VBUS), J1.B9 (VBUS), Q1.1 (G), R178.1, U6.3 (VI)

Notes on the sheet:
REV2 TODO: [X] fix USB lines [X] replace MCU (need more ram/flash) [X] move both buttons to available interrupt pins
100k/20k => 2.4V threshold

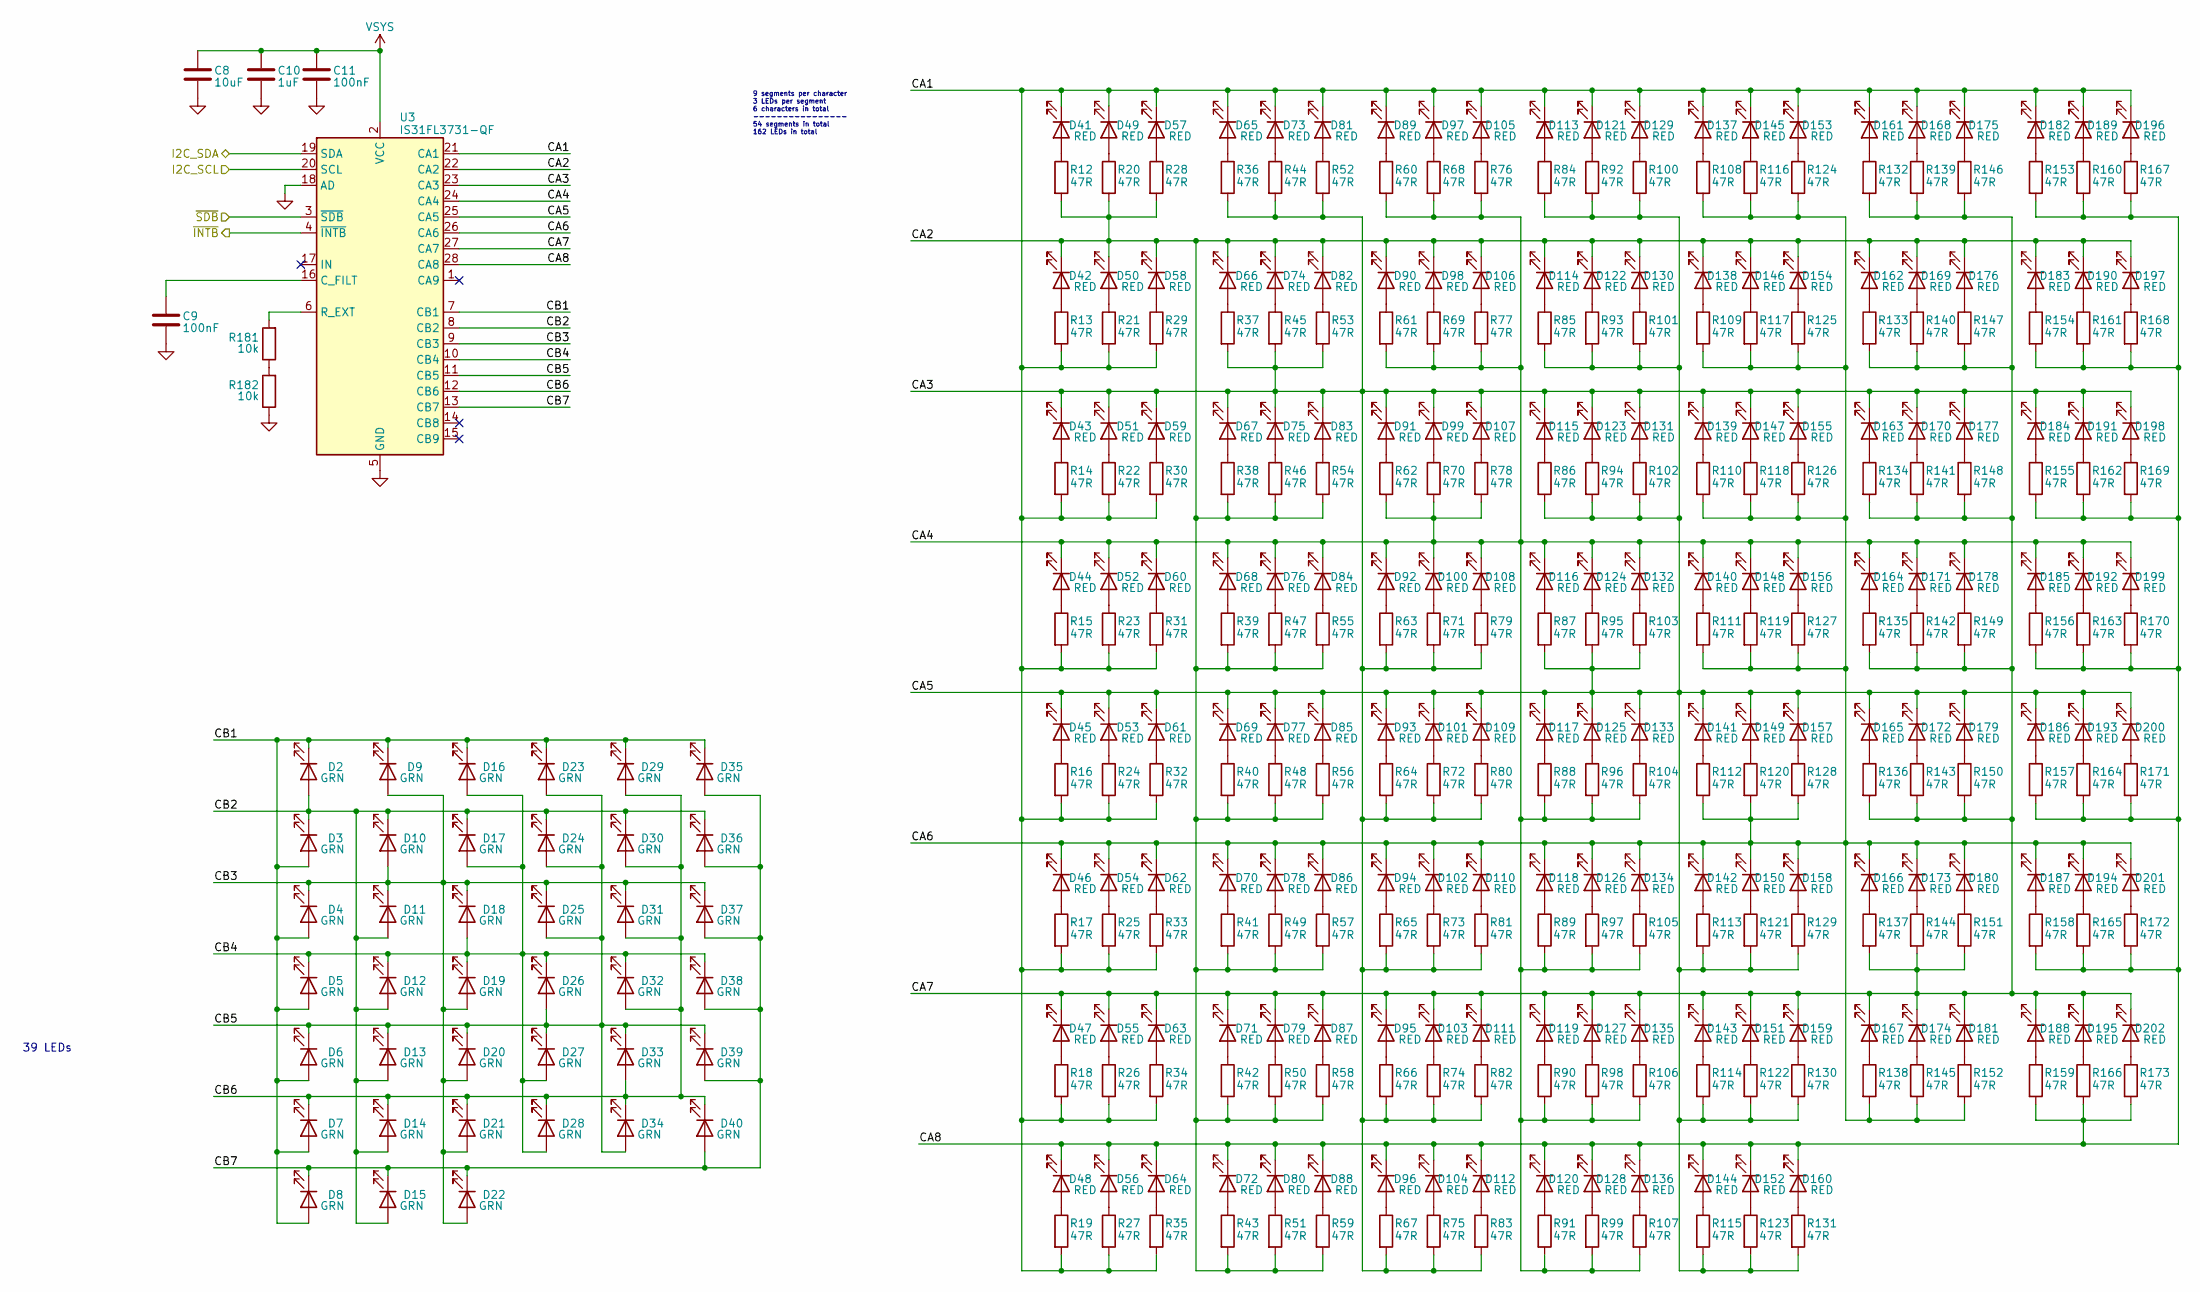
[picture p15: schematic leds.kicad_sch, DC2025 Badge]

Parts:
C8: 10uF; C_0603_1608Metric; MPN GRM188Z71A106MA73D; JLCPCB# C237435
C9, C11: 100nF; C_0402_1005Metric; MPN CL05B104KB54PNC; JLCPCB# C307331
C10: 1uF; C_0603_1608Metric; MPN 0603B105K250NT; JLCPCB# C59302
D2, D3, D4, D5, D6, D7, D8, D9, D10, D11, D12, D13, D14, D15, D16, D17, D18, D19, D20, D21, D22, D23, D24, D25, D26, D27, D28, D29, D30, D31, D32, D33, D34, D35, D36, D37, D38, D39, D40: GRN; LED_0603_1608Metric; MPN XL-1608UGC-04; JLCPCB# C965804
D41, D42, D43, D44, D45, D46, D47, D48, D49, D50, D51, D52, D53, D54, D55, D56, D57, D58, D59, D60, D61, D62, D63, D64, D65, D66, D67, D68, D69, D70, D71, D72, D73, D74, D75, D76, D77, D78, D79, D80, D81, D82, D83, D84, D85, D86, D87, D88, D89, D90, D91, D92, D93, D94, D95, D96, D97, D98, D99, D100, D101, D102, D103, D104, D105, D106, D107, D108, D109, D110, D111, D112, D113, D114, D115, D116, D117, D118, D119, D120, D121, D122, D123, D124, D125, D126, D127, D128, D129, D130, D131, D132, D133, D134, D135, D136, D137, D138, D139, D140, D141, D142, D143, D144, D145, D146, D147, D148, D149, D150, D151, D152, D153, D154, D155, D156, D157, D158, D159, D160, D161, D162, D163, D164, D165, D166, D167, D168, D169, D170, D171, D172, D173, D174, D175, D176, D177, D178, D179, D180, D181, D182, D183, D184, D185, D186, D187, D188, D189, D190, D191, D192, D193, D194, D195, D196, D197, D198, D199, D200, D201, D202: RED; LED_0603_1608Metric; MPN XL-1608SURC-06; JLCPCB# C965799
R12, R13, R14, R15, R16, R17, R18, R19, R20, R21, R22, R23, R24, R25, R26, R27, R28, R29, R30, R31, R32, R33, R34, R35, R36, R37, R38, R39, R40, R41, R42, R43, R44, R45, R46, R47, R48, R49, R50, R51, R52, R53, R54, R55, R56, R57, R58, R59, R60, R61, R62, R63, R64, R65, R66, R67, R68, R69, R70, R71, R72, R73, R74, R75, R76, R77, R78, R79, R80, R81, R82, R83, R84, R85, R86, R87, R88, R89, R90, R91, R92, R93, R94, R95, R96, R97, R98, R99, R100, R101, R102, R103, R104, R105, R106, R107, R108, R109, R110, R111, R112, R113, R114, R115, R116, R117, R118, R119, R120, R121, R122, R123, R124, R125, R126, R127, R128, R129, R130, R131, R132, R133, R134, R135, R136, R137, R138, R139, R140, R141, R142, R143, R144, R145, R146, R147, R148, R149, R150, R151, R152, R153, R154, R155, R156, R157, R158, R159, R160, R161, R162, R163, R164, R165, R166, R167, R168, R169, R170, R171, R172, R173: 47R; R_0402_1005Metric; MPN 0402WGF470JTCE; JLCPCB# C25118
R181, R182: 10k; R_0402_1005Metric; MPN 0402WGF1002TCE; JLCPCB# C25744
U3: IS31FL3731-QF; QFN-28-1EP_4x4mm_P0.4mm_EP2.3x2.3mm; MPN IS31FL3731-QFLS2-TR; JLCPCB# C191206

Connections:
/I2C_SCL: U3.20 (SCL); also elsewhere on the board
/I2C_SDA: U3.19 (SDA); also elsewhere on the board
/LEDs/CA1: D41.1 (K), D49.1 (K), D57.1 (K), D65.1 (K), D73.1 (K), D81.1 (K), D89.1 (K), D97.1 (K), D105.1 (K), D113.1 (K), D121.1 (K), D129.1 (K), D137.1 (K), D145.1 (K), D153.1 (K), D161.1 (K), D168.1 (K), D175.1 (K), D182.1 (K), D189.1 (K), D196.1 (K), R13.2, R14.2, R15.2, R16.2, R17.2, R18.2, R19.2, R21.2, R22.2, R23.2, R24.2, R25.2, R26.2, R27.2, R29.2, R30.2, R31.2, R32.2, R33.2, R34.2, R35.2, U3.21 (CA1)
/LEDs/CA2: D42.1 (K), D50.1 (K), D58.1 (K), D66.1 (K), D74.1 (K), D82.1 (K), D90.1 (K), D98.1 (K), D106.1 (K), D114.1 (K), D122.1 (K), D130.1 (K), D138.1 (K), D146.1 (K), D154.1 (K), D162.1 (K), D169.1 (K), D176.1 (K), D183.1 (K), D190.1 (K), D197.1 (K), R12.2, R20.2, R28.2, R38.2, R39.2, R40.2, R41.2, R42.2, R43.2, R46.2, R47.2, R48.2, R49.2, R50.2, R51.2, R54.2, R55.2, R56.2, R57.2, R58.2, R59.2, U3.22 (CA2)
/LEDs/CA3: D43.1 (K), D51.1 (K), D59.1 (K), D67.1 (K), D75.1 (K), D83.1 (K), D91.1 (K), D99.1 (K), D107.1 (K), D115.1 (K), D123.1 (K), D131.1 (K), D139.1 (K), D147.1 (K), D155.1 (K), D163.1 (K), D170.1 (K), D177.1 (K), D184.1 (K), D191.1 (K), D198.1 (K), R36.2, R37.2, R44.2, R45.2, R52.2, R53.2, R63.2, R64.2, R65.2, R66.2, R67.2, R71.2, R72.2, R73.2, R74.2, R75.2, R79.2, R80.2, R81.2, R82.2, R83.2, U3.23 (CA3)
/LEDs/CA4: D44.1 (K), D52.1 (K), D60.1 (K), D68.1 (K), D76.1 (K), D84.1 (K), D92.1 (K), D100.1 (K), D108.1 (K), D116.1 (K), D124.1 (K), D132.1 (K), D140.1 (K), D148.1 (K), D156.1 (K), D164.1 (K), D171.1 (K), D178.1 (K), D185.1 (K), D192.1 (K), D199.1 (K), R60.2, R61.2, R62.2, R68.2, R69.2, R70.2, R76.2, R77.2, R78.2, R88.2, R89.2, R90.2, R91.2, R96.2, R97.2, R98.2, R99.2, R104.2, R105.2, R106.2, R107.2, U3.24 (CA4)
/LEDs/CA5: D45.1 (K), D53.1 (K), D61.1 (K), D69.1 (K), D77.1 (K), D85.1 (K), D93.1 (K), D101.1 (K), D109.1 (K), D117.1 (K), D125.1 (K), D133.1 (K), D141.1 (K), D149.1 (K), D157.1 (K), D165.1 (K), D172.1 (K), D179.1 (K), D186.1 (K), D193.1 (K), D200.1 (K), R84.2, R85.2, R86.2, R87.2, R92.2, R93.2, R94.2, R95.2, R100.2, R101.2, R102.2, R103.2, R113.2, R114.2, R115.2, R121.2, R122.2, R123.2, R129.2, R130.2, R131.2, U3.25 (CA5)
/LEDs/CA6: D46.1 (K), D54.1 (K), D62.1 (K), D70.1 (K), D78.1 (K), D86.1 (K), D94.1 (K), D102.1 (K), D110.1 (K), D118.1 (K), D126.1 (K), D134.1 (K), D142.1 (K), D150.1 (K), D158.1 (K), D166.1 (K), D173.1 (K), D180.1 (K), D187.1 (K), D194.1 (K), D201.1 (K), R108.2, R109.2, R110.2, R111.2, R112.2, R116.2, R117.2, R118.2, R119.2, R120.2, R124.2, R125.2, R126.2, R127.2, R128.2, R138.2, R145.2, R152.2, U3.26 (CA6)
/LEDs/CA7: D47.1 (K), D55.1 (K), D63.1 (K), D71.1 (K), D79.1 (K), D87.1 (K), D95.1 (K), D103.1 (K), D111.1 (K), D119.1 (K), D127.1 (K), D135.1 (K), D143.1 (K), D151.1 (K), D159.1 (K), D167.1 (K), D174.1 (K), D181.1 (K), D188.1 (K), D195.1 (K), D202.1 (K), R132.2, R133.2, R134.2, R135.2, R136.2, R137.2, R139.2, R140.2, R141.2, R142.2, R143.2, R144.2, R146.2, R147.2, R148.2, R149.2, R150.2, R151.2, U3.27 (CA7)
/LEDs/CA8: D48.1 (K), D56.1 (K), D64.1 (K), D72.1 (K), D80.1 (K), D88.1 (K), D96.1 (K), D104.1 (K), D112.1 (K), D120.1 (K), D128.1 (K), D136.1 (K), D144.1 (K), D152.1 (K), D160.1 (K), R153.2, R154.2, R155.2, R156.2, R157.2, R158.2, R159.2, R160.2, R161.2, R162.2, R163.2, R164.2, R165.2, R166.2, R167.2, R168.2, R169.2, R170.2, R171.2, R172.2, R173.2, U3.28 (CA8)
/LEDs/CB1: D2.1 (K), D3.2 (A), D4.2 (A), D5.2 (A), D6.2 (A), D7.2 (A), D8.2 (A), D9.1 (K), D16.1 (K), D23.1 (K), D29.1 (K), D35.1 (K), U3.7 (CB1)
/LEDs/CB2: D2.2 (A), D3.1 (K), D10.1 (K), D11.2 (A), D12.2 (A), D13.2 (A), D14.2 (A), D15.2 (A), D17.1 (K), D24.1 (K), D30.1 (K), D36.1 (K), U3.8 (CB2)
/LEDs/CB3: D4.1 (K), D9.2 (A), D10.2 (A), D11.1 (K), D18.1 (K), D19.2 (A), D20.2 (A), D21.2 (A), D22.2 (A), D25.1 (K), D31.1 (K), D37.1 (K), U3.9 (CB3)
/LEDs/CB4: D5.1 (K), D12.1 (K), D16.2 (A), D17.2 (A), D18.2 (A), D19.1 (K), D26.1 (K), D27.2 (A), D28.2 (A), D32.1 (K), D38.1 (K), U3.10 (CB4)
/LEDs/CB5: D6.1 (K), D13.1 (K), D20.1 (K), D23.2 (A), D24.2 (A), D25.2 (A), D26.2 (A), D27.1 (K), D33.1 (K), D34.2 (A), D39.1 (K), U3.11 (CB5)
/LEDs/CB6: D7.1 (K), D14.1 (K), D21.1 (K), D28.1 (K), D29.2 (A), D30.2 (A), D31.2 (A), D32.2 (A), D33.2 (A), D34.1 (K), D40.1 (K), U3.12 (CB6)
/LEDs/CB7: D8.1 (K), D15.1 (K), D22.1 (K), D35.2 (A), D36.2 (A), D37.2 (A), D38.2 (A), D39.2 (A), D40.2 (A), U3.13 (CB7)
/LEDs/~INTB: U3.4 (~INTB); also elsewhere on the board
/LEDs/~SDB: U3.3 (~SDB); also elsewhere on the board
GND: C8.2, C9.2, C10.2, C11.2, R182.1, U3.5 (GND), U3.18 (AD), U3.29 (GND); also elsewhere on the board
unnamed: D41.2 (A), R12.1
unnamed: D42.2 (A), R13.1
unnamed: D43.2 (A), R14.1
unnamed: D44.2 (A), R15.1
unnamed: D45.2 (A), R16.1
unnamed: D46.2 (A), R17.1
unnamed: D47.2 (A), R18.1
unnamed: D48.2 (A), R19.1
unnamed: D49.2 (A), R20.1
unnamed: D50.2 (A), R21.1
unnamed: D51.2 (A), R22.1
unnamed: D52.2 (A), R23.1
unnamed: D53.2 (A), R24.1
unnamed: D54.2 (A), R25.1
unnamed: D55.2 (A), R26.1
unnamed: D56.2 (A), R27.1
unnamed: D57.2 (A), R28.1
unnamed: D58.2 (A), R29.1
unnamed: D59.2 (A), R30.1
unnamed: D60.2 (A), R31.1
unnamed: D61.2 (A), R32.1
unnamed: D62.2 (A), R33.1
unnamed: D63.2 (A), R34.1
unnamed: D64.2 (A), R35.1
unnamed: D65.2 (A), R36.1
unnamed: D66.2 (A), R37.1
unnamed: D67.2 (A), R38.1
unnamed: D68.2 (A), R39.1
unnamed: D69.2 (A), R40.1
unnamed: D70.2 (A), R41.1
unnamed: D71.2 (A), R42.1
unnamed: D72.2 (A), R43.1
unnamed: D73.2 (A), R44.1
unnamed: D74.2 (A), R45.1
unnamed: D75.2 (A), R46.1
unnamed: D76.2 (A), R47.1
unnamed: D77.2 (A), R48.1
unnamed: D78.2 (A), R49.1
unnamed: D79.2 (A), R50.1
unnamed: D80.2 (A), R51.1
unnamed: D81.2 (A), R52.1
unnamed: D82.2 (A), R53.1
unnamed: D83.2 (A), R54.1
unnamed: D84.2 (A), R55.1
unnamed: D85.2 (A), R56.1
unnamed: D86.2 (A), R57.1
unnamed: D87.2 (A), R58.1
unnamed: D88.2 (A), R59.1
unnamed: D89.2 (A), R60.1
unnamed: D90.2 (A), R61.1
unnamed: D91.2 (A), R62.1
unnamed: D92.2 (A), R63.1
unnamed: D93.2 (A), R64.1
unnamed: D94.2 (A), R65.1
unnamed: D95.2 (A), R66.1
unnamed: D96.2 (A), R67.1
unnamed: D97.2 (A), R68.1
unnamed: D98.2 (A), R69.1
unnamed: D99.2 (A), R70.1
unnamed: D100.2 (A), R71.1
unnamed: D101.2 (A), R72.1
unnamed: D102.2 (A), R73.1
unnamed: D103.2 (A), R74.1
unnamed: D104.2 (A), R75.1
unnamed: D105.2 (A), R76.1
unnamed: D106.2 (A), R77.1
unnamed: D107.2 (A), R78.1
unnamed: D108.2 (A), R79.1
unnamed: D109.2 (A), R80.1
unnamed: D110.2 (A), R81.1
unnamed: D111.2 (A), R82.1
unnamed: D112.2 (A), R83.1
unnamed: D113.2 (A), R84.1
unnamed: D114.2 (A), R85.1
unnamed: D115.2 (A), R86.1
unnamed: D116.2 (A), R87.1
unnamed: D117.2 (A), R88.1
unnamed: D118.2 (A), R89.1
unnamed: D119.2 (A), R90.1
unnamed: D120.2 (A), R91.1
unnamed: D121.2 (A), R92.1
unnamed: D122.2 (A), R93.1
unnamed: D123.2 (A), R94.1
unnamed: D124.2 (A), R95.1
unnamed: D125.2 (A), R96.1
unnamed: D126.2 (A), R97.1
unnamed: D127.2 (A), R98.1
unnamed: D128.2 (A), R99.1
unnamed: D129.2 (A), R100.1
unnamed: D130.2 (A), R101.1
unnamed: D131.2 (A), R102.1
unnamed: D132.2 (A), R103.1
unnamed: D133.2 (A), R104.1
unnamed: D134.2 (A), R105.1
unnamed: D135.2 (A), R106.1
unnamed: D136.2 (A), R107.1
unnamed: D137.2 (A), R108.1
unnamed: D138.2 (A), R109.1
unnamed: D139.2 (A), R110.1
unnamed: D140.2 (A), R111.1
unnamed: D141.2 (A), R112.1
unnamed: D142.2 (A), R113.1
unnamed: D143.2 (A), R114.1
unnamed: D144.2 (A), R115.1
unnamed: D145.2 (A), R116.1
unnamed: D146.2 (A), R117.1
unnamed: D147.2 (A), R118.1
unnamed: D148.2 (A), R119.1
unnamed: D149.2 (A), R120.1
unnamed: D150.2 (A), R121.1
unnamed: D151.2 (A), R122.1
unnamed: D152.2 (A), R123.1
unnamed: D153.2 (A), R124.1
unnamed: D154.2 (A), R125.1
unnamed: D155.2 (A), R126.1
unnamed: D156.2 (A), R127.1
unnamed: D157.2 (A), R128.1
unnamed: D158.2 (A), R129.1
unnamed: D159.2 (A), R130.1
unnamed: D160.2 (A), R131.1
unnamed: D161.2 (A), R132.1
unnamed: D162.2 (A), R133.1
unnamed: D163.2 (A), R134.1
unnamed: D164.2 (A), R135.1
unnamed: D165.2 (A), R136.1
unnamed: D166.2 (A), R137.1
unnamed: D167.2 (A), R138.1
unnamed: D168.2 (A), R139.1
unnamed: D169.2 (A), R140.1
unnamed: D170.2 (A), R141.1
unnamed: D171.2 (A), R142.1
unnamed: D172.2 (A), R143.1
unnamed: D173.2 (A), R144.1
unnamed: D174.2 (A), R145.1
unnamed: D175.2 (A), R146.1
unnamed: D176.2 (A), R147.1
unnamed: D177.2 (A), R148.1
unnamed: D178.2 (A), R149.1
unnamed: D179.2 (A), R150.1
unnamed: D180.2 (A), R151.1
unnamed: D181.2 (A), R152.1
unnamed: D182.2 (A), R153.1
unnamed: D183.2 (A), R154.1
unnamed: D184.2 (A), R155.1
unnamed: D185.2 (A), R156.1
unnamed: D186.2 (A), R157.1
unnamed: D187.2 (A), R158.1
unnamed: D188.2 (A), R159.1
unnamed: D189.2 (A), R160.1
unnamed: D190.2 (A), R161.1
unnamed: D191.2 (A), R162.1
unnamed: D192.2 (A), R163.1
unnamed: D193.2 (A), R164.1
unnamed: D194.2 (A), R165.1
unnamed: D195.2 (A), R166.1
unnamed: D196.2 (A), R167.1
unnamed: D197.2 (A), R168.1
unnamed: D198.2 (A), R169.1
unnamed: D199.2 (A), R170.1
unnamed: D200.2 (A), R171.1
unnamed: D201.2 (A), R172.1
unnamed: D202.2 (A), R173.1
unnamed: R181.1, R182.2
unnamed: C9.1, U3.16 (C_FILT)
unnamed: R181.2, U3.6 (R_EXT)
VSYS: C8.1, C10.1, C11.1, U3.2 (VCC); also elsewhere on the board

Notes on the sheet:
9 segments per character 3 LEDs per segment 6 characters in total ---------------- 54 segments in total 162 LEDs in total
39 LEDs

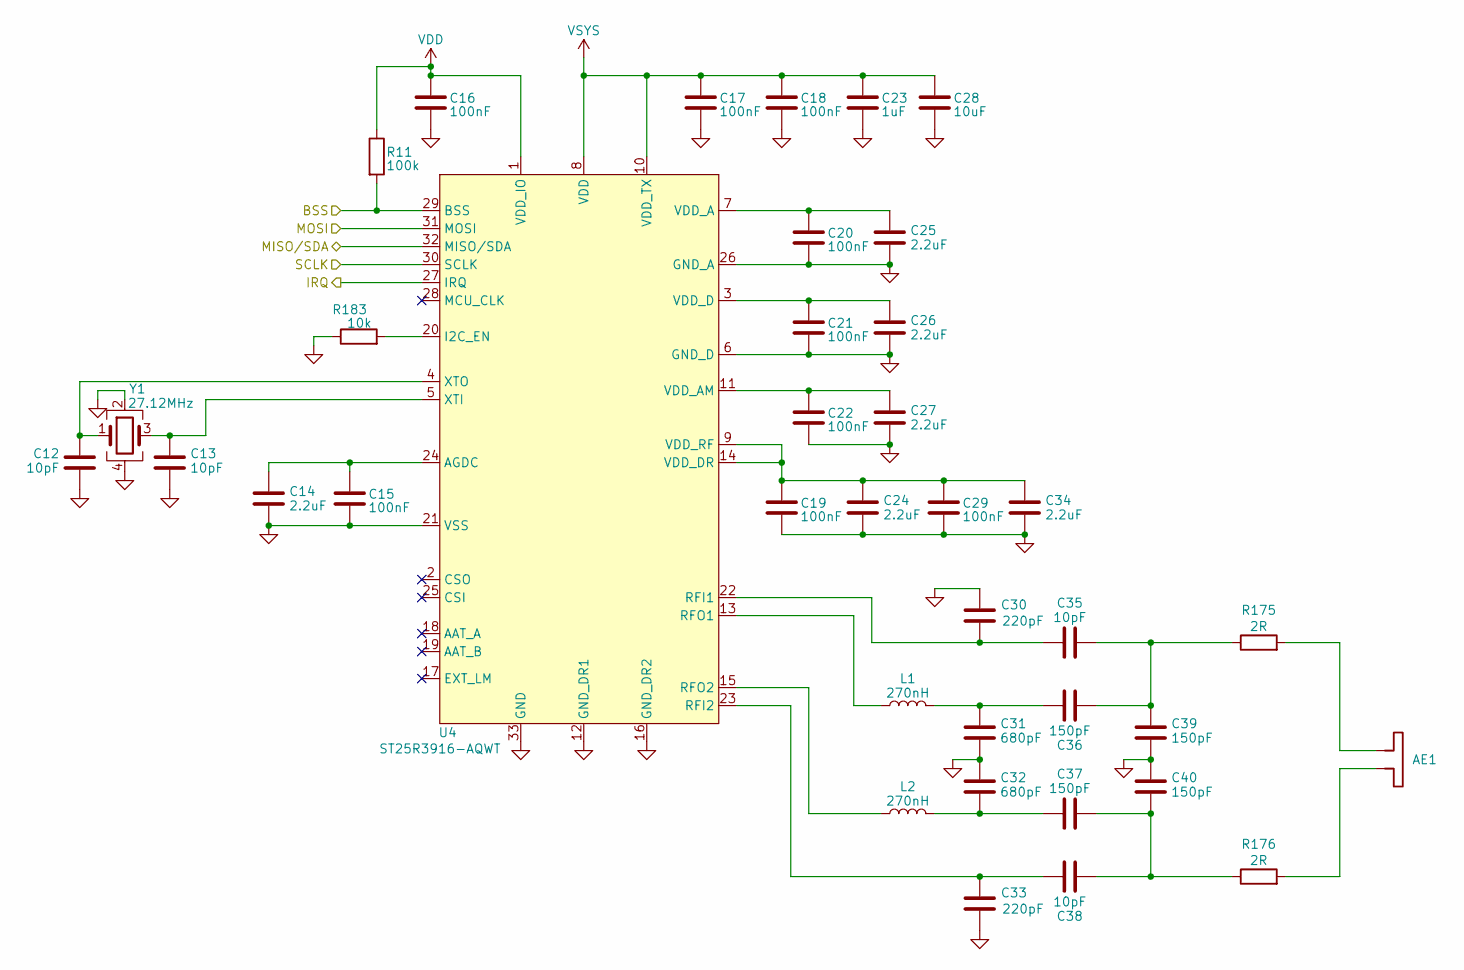
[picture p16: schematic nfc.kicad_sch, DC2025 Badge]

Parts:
AE1: Antenna; nfc_antenna
C12, C13, C35, C38: 10pF; C_0402_1005Metric; MPN CL05C100JB5NNNC; JLCPCB# C32949
C14, C24, C25, C26, C27, C34: 2.2uF; C_0603_1608Metric; MPN CL10A225KO8NNNC; JLCPCB# C23630
C15, C16, C17, C18, C19, C20, C21, C22, C29: 100nF; C_0402_1005Metric; MPN CL05B104KB54PNC; JLCPCB# C307331
C23: 1uF; C_0603_1608Metric; MPN 0603B105K250NT; JLCPCB# C59302
C28: 10uF; C_0603_1608Metric; MPN GRM188Z71A106MA73D; JLCPCB# C237435
C30, C33: 220pF; C_0402_1005Metric; MPN 0402B221K500NT; JLCPCB# C1530
C31, C32: 680pF; C_0402_1005Metric; MPN 0402B681K500NT; JLCPCB# C1541
C36, C37, C39, C40: 150pF; C_0402_1005Metric; MPN 0402B151K500NT; JLCPCB# C1527
L1, L2: 270nH; L_0402_1005Metric_Pad0.77x0.64mm_HandSolder; MPN LQB15NNR27K10D; JLCPCB# C907954
R11: 100k; R_0402_1005Metric; MPN 0402WGF1003TCE; JLCPCB# C25741
R175, R176: 2R; R_0402_1005Metric; MPN WR04X2R0JTL; JLCPCB# C170397
R183: 10k; R_0402_1005Metric; MPN 0402WGF1002TCE; JLCPCB# C25744
U4: ST25R3916-AQWT; UFQFPN-32-1EP_5x5mm_P0.5mm_EP3.5x3.5mm; MPN ST25R3916-AQWT; JLCPCB# C2908147
Y1: 27.12MHz; Crystal_SMD_3225-4Pin_3.2x2.5mm; MPN X32252712MMB4SI; JLCPCB# C29975

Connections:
/NFC/BSS: R11.2, U4.29 (BSS); also elsewhere on the board
/NFC/IRQ: U4.27 (IRQ); also elsewhere on the board
/SPI_MISO: U4.32 (MISO/SDA); also elsewhere on the board
/SPI_MOSI: U4.31 (MOSI); also elsewhere on the board
/SPI_SCK: U4.30 (SCLK); also elsewhere on the board
GND: C12.1, C13.1, C14.2, C15.2, C16.2, C17.2, C18.2, C19.2, C20.2, C21.2, C22.2, C23.2, C24.2, C25.2, C26.2, C27.2, C28.2, C29.2, C30.2, C31.2, C32.1, C33.1, C34.2, C39.2, C40.1, R183.1, U4.6 (GND_D), U4.12 (GND_DR1), U4.16 (GND_DR2), U4.21 (VSS), U4.26 (GND_A), U4.33 (GND), Y1.2, Y1.4; also elsewhere on the board
unnamed: AE1.1, R175.2
unnamed: AE1.2, R176.2
unnamed: C31.1, C36.1, L1.2
unnamed: C32.2, C37.1, L2.2
unnamed: C35.2, C36.2, C39.1, R175.1
unnamed: C37.2, C38.2, C40.2, R176.1
unnamed: C14.1, C15.1, U4.24 (AGDC)
unnamed: R183.2, U4.20 (I2C_EN)
unnamed: C30.1, C35.1, U4.22 (RFI1)
unnamed: C33.2, C38.1, U4.23 (RFI2)
unnamed: L1.1, U4.13 (RFO1)
unnamed: L2.1, U4.15 (RFO2)
unnamed: C20.1, C25.1, U4.7 (VDD_A)
unnamed: C22.1, C27.1, U4.11 (VDD_AM)
unnamed: C21.1, C26.1, U4.3 (VDD_D)
unnamed: C19.1, C24.1, C29.1, C34.1, U4.9 (VDD_RF), U4.14 (VDD_DR)
unnamed: C13.2, U4.5 (XTI), Y1.3
unnamed: C12.2, U4.4 (XTO), Y1.1
VDD: C16.1, R11.1, U4.1 (VDD_IO); also elsewhere on the board
VSYS: C17.1, C18.1, C23.1, C28.1, U4.8 (VDD), U4.10 (VDD_TX); also elsewhere on the board

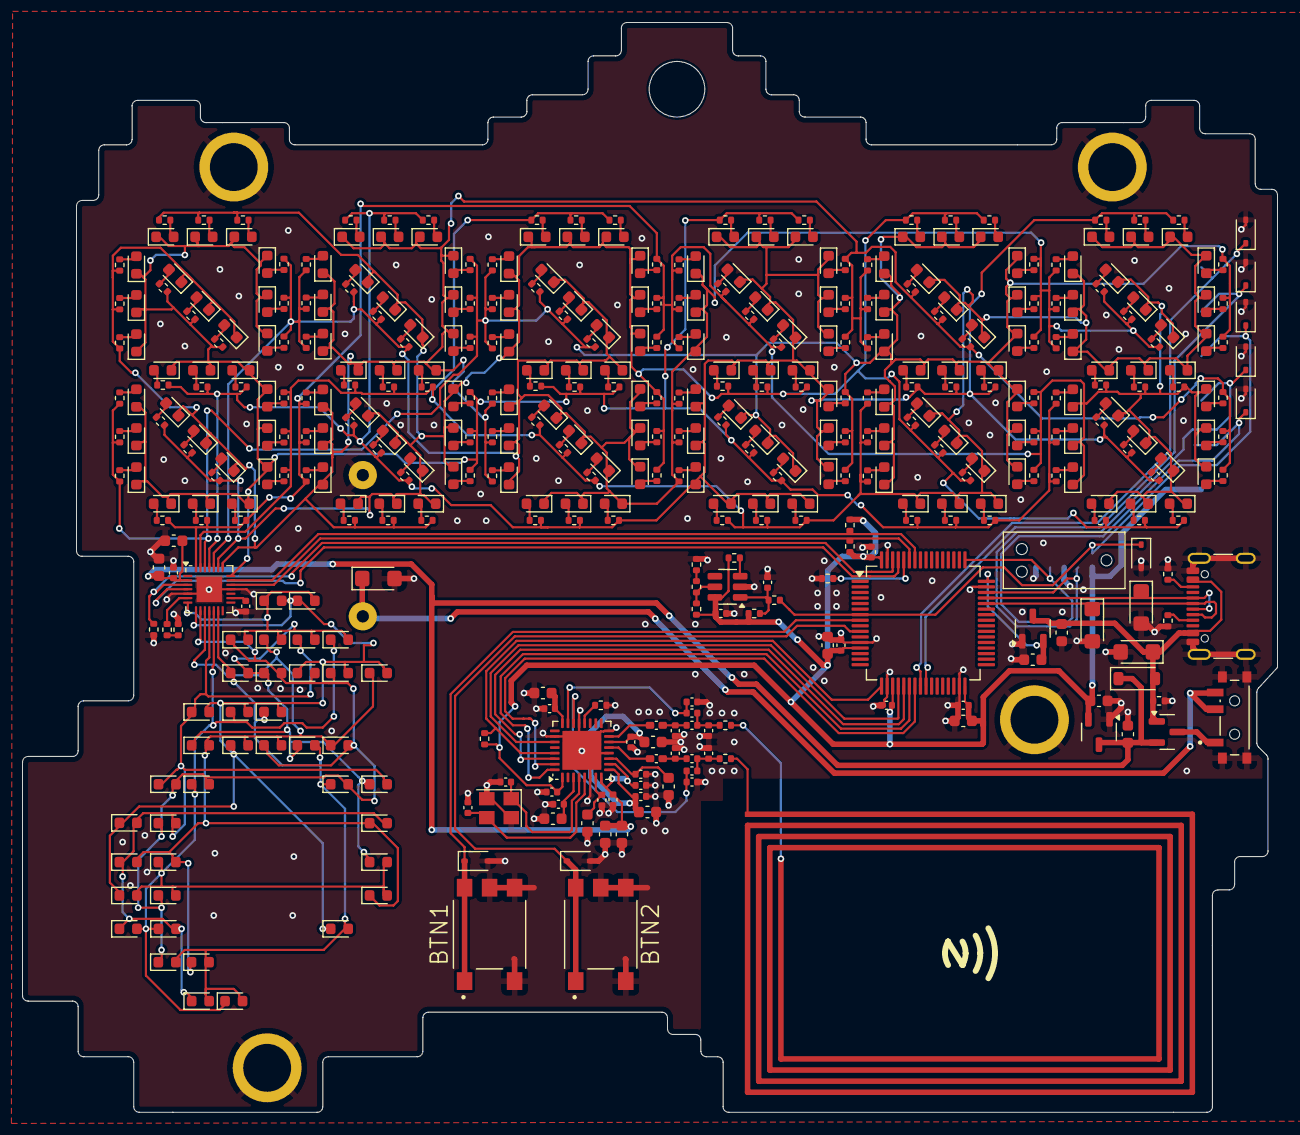
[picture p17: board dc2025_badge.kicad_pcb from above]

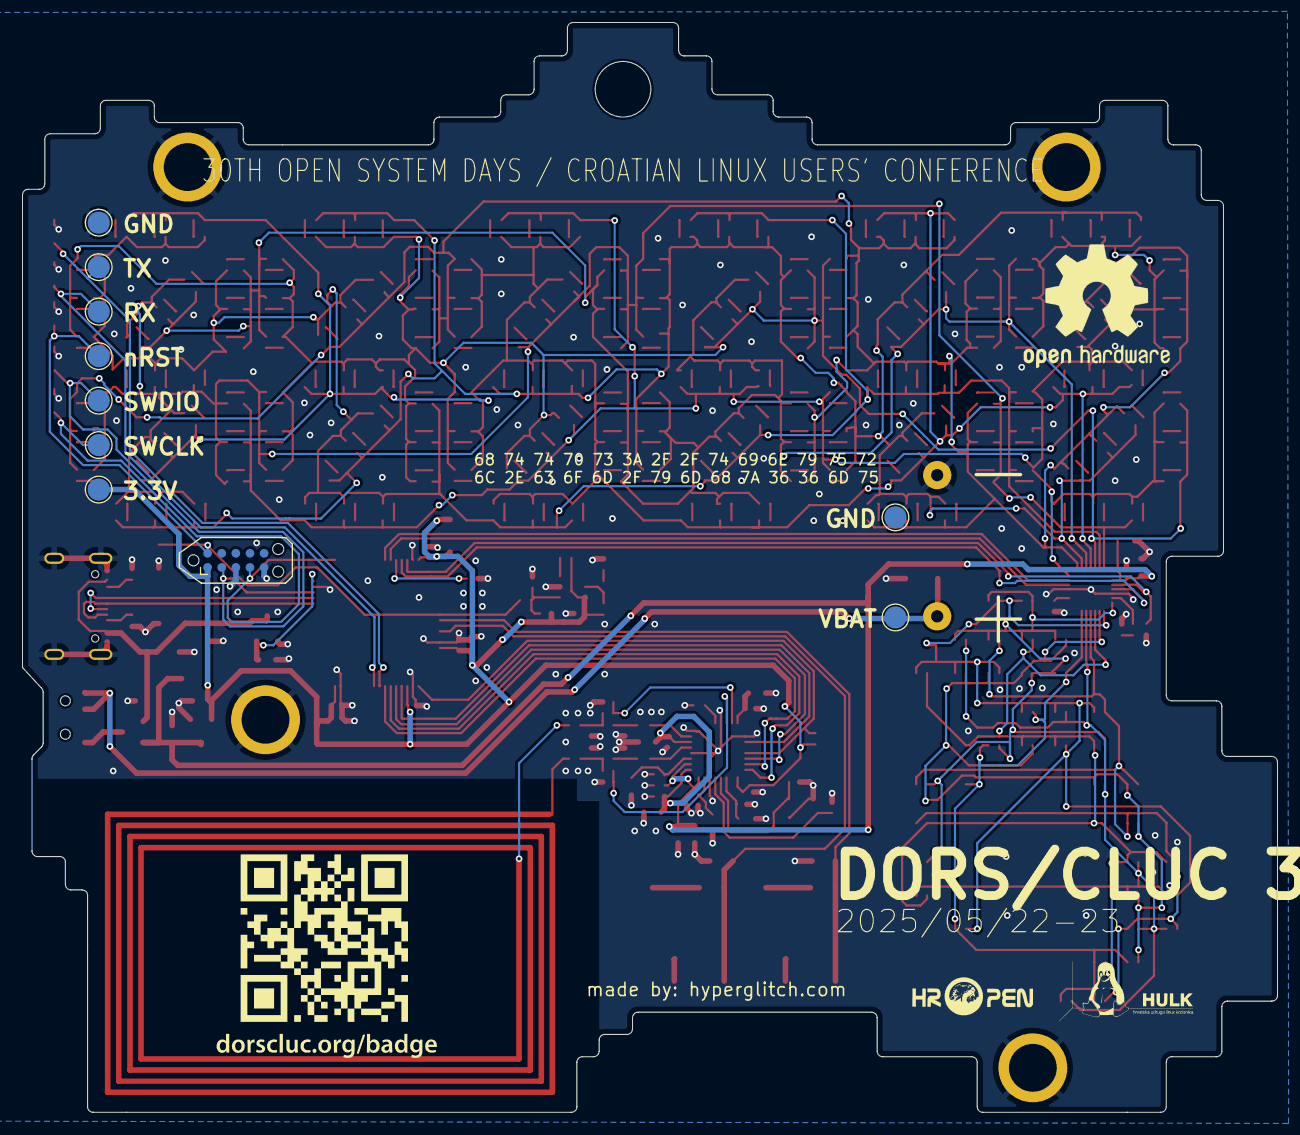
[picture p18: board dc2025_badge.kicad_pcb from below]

Board: 2 copper layers, 112.9 x 98.0 mm, 471 parts (11 on the bottom side), 230 nets.

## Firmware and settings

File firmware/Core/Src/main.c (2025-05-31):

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
/* Includes ------------------------------------------------------------------*/
#include "main.h"
#include "usb_device.h"

/* USER CODE BEGIN Includes */
#include <stdbool.h>
#include <string.h>
#include <stdarg.h>
#include "usbd_cdc_if.h"

#include "nfc.h"
#include "logger.h"
#include "instance_id.h"


#include "shell_menu.h"

/* USER CODE END Includes */

I2C_HandleTypeDef hi2c1;

UART_HandleTypeDef hlpuart1;

RTC_HandleTypeDef hrtc;

TIM_HandleTypeDef htim6;

/* USER CODE BEGIN PV */

typedef enum{
	  OPMODE_CONFERENCE,
	  OPMODE_CLOCK,
	  OPMODE_NOTIFIER,
	  OPMODE_GAME,
	  OPMODE_TEST,
} operation_mode_t;

volatile operation_mode_t g_operation_mode;

// config items
typedef enum{
	SETT_HEADER = 0,
	SETT_CHECKSUM,
	SETT_MODE,
	SETT_CLOCK_RELOAD,
	SETT_CLOCK_CHIME,
	SETT_CLOCK_SHOW_SECONDS,
	SETT_BRIGHTNESS,
	SETT_SCROLL_SPEED,

	SETT_SCROLL_TEXT0,
	SETT_SCROLL_TEXT1,
	SETT_SCROLL_TEXT2,
	SETT_SCROLL_TEXT3,
	SETT_SCROLL_TEXT4,
	SETT_SCROLL_TEXT5,
	SETT_SCROLL_TEXT6,
	SETT_SCROLL_TEXT7,

	SETT_THUNT_DATA0,
	SETT_THUNT_DATA1,
	SETT_THUNT_DATA2,
	SETT_THUNT_DATA3,
	SETT_OTHERS_DATA0,
	SETT_OTHERS_DATA1,
	SETT_OTHERS_DATA2,
	SETT_OTHERS_DATA3,
	SETT_OTHERS_DATA4,
	SETT_OTHERS_DATA5,
	SETT_OTHERS_DATA6,
	SETT_OTHERS_DATA7,

	SETT_CONFIG_VERSION,
	SETT_CONFIG_END

} setting_item_t;

// default config
volatile uint32_t g_config[] = {
	0,				// SETT_HEADER
	0,				// SETT_CHECKSUM
	OPMODE_TEST,	// SETT_MODE
	3200,			// SETT_CLOCK_RELOAD
	1,				// SETT_CLOCK_CHIME
	1,				// SETT_CLOCK_SHOW_SECONDS
	20,				// SETT_BRIGHNESS
	300,			// SETT_SCROLL_SPEED

	0x53524f44,		// SETT_SCROLL_TEXT0, 	"SROD"
	0x554c4320,		// SETT_SCROLL_TEXT1, 	"ULC "
	0x30322043,		// SETT_SCROLL_TEXT2,	"02 C"
	0x00003532,		// SETT_SCROLL_TEXT3,	"..52"
	0x00000000,		// SETT_SCROLL_TEXT4
	0x00000000,		// SETT_SCROLL_TEXT5
	0x00000000,		// SETT_SCROLL_TEXT6
	0x00000000,		// SETT_SCROLL_TEXT7

	0,				// SETT_THUNT_DATA0
	0,				// SETT_THUNT_DATA1
	0,				// SETT_THUNT_DATA2
	0,				// SETT_THUNT_DATA3

	0, 				// SETT_OTHERS_DATA0
	0, 				// SETT_OTHERS_DATA1
	0, 				// SETT_OTHERS_DATA2
	0, 				// SETT_OTHERS_DATA3
	0, 				// SETT_OTHERS_DATA4
	0, 				// SETT_OTHERS_DATA5
	0, 				// SETT_OTHERS_DATA6
	0, 				// SETT_OTHERS_DATA7

	0,				// SETT_CONFIG_VERSION
	0xff			// SETT_CONFIG_END
};

volatile uint32_t g_config_loaded[sizeof(g_config)/sizeof(uint32_t)];


typedef struct{
	bool manual;
	char screen[7];
	char disp_buffer[32];
	uint32_t last_screen_update;
	int32_t txt_pos;
	int32_t txt_len;

	char disp_temp_buffer[32];
	uint32_t disp_temp_duration;
	uint32_t disp_temp_started;
	bool disp_temp_changed;
	bool disp_temp_active;
	int disp_temp_delay;
	uint8_t brightness;
} disp_text_t;

volatile disp_text_t disp_conf;


typedef struct{
	int thunt;
	int bcounter;
} quest_t;


volatile quest_t quest_data = {
		.thunt = 0,
		.bcounter = 0
};


//const uint32_t data_flash_addr = 0x8000000UL + 126*1024;
const uint32_t data_flash_addr = 0x8000000UL + 125*1024;
const uint32_t data_config_header = 0x1337;


uint32_t crc32(const uint8_t *data, size_t length) {
    uint32_t crc = 0xFFFFFFFF;
    for (size_t i = 0; i < length; i++) {
        crc ^= data[i];
        for (int j = 0; j < 8; j++)
            crc = (crc >> 1) ^ (0xEDB88320 & -(crc & 1));
    }
    return ~crc;
}


// -------------------------------------------------------------------
// configuration handling

bool configuration_load(){
	uint32_t address;

	// load the config and calculate sum
	address = data_flash_addr;
	for(int i=0; i<SETT_CONFIG_END; i++){
		g_config_loaded[i] = *(__IO uint32_t *)(address+4*i);
	}

	const uint32_t checksum = crc32((const uint8_t*)&g_config_loaded[SETT_MODE], (SETT_CONFIG_VERSION-SETT_MODE)*4);

	// check if valid
	if(g_config_loaded[SETT_HEADER]!=data_config_header){
		bprintf("No config found\r\n");
		return false;
	}
	if(g_config_loaded[SETT_CHECKSUM]!=checksum){
		bprintf("Config checksum mismatch\r\n");
		return false;
	}

	// copy to main config
	memcpy((uint32_t*)g_config, (uint32_t*)g_config_loaded, SETT_CONFIG_END*sizeof(uint32_t));

	bprintf("Config loaded\r\n");
	return true;
}


bool configuration_save(bool clear){
	uint32_t address;

	// update config checksum
	const uint32_t checksum = crc32((const uint8_t*)&g_config[SETT_MODE], (SETT_CONFIG_VERSION-SETT_MODE)*4);

	g_config[SETT_HEADER] = data_config_header;
	g_config[SETT_CHECKSUM] = checksum;
	g_config[SETT_CONFIG_VERSION]++;

	if(clear){
		// invalidate the header in order to reset the configuration
		g_config[SETT_HEADER] = 0;
	}

	if(HAL_FLASH_Unlock()!=HAL_OK){
		bprintf("error unlocking flash\r\n");
		return false;
	}

	// erase flash page
	__HAL_FLASH_CLEAR_FLAG(FLASH_FLAG_OPTVERR); // Clear OPTVERR bit set on virgin samples (maybe not needed)

	FLASH_EraseInitTypeDef EraseInitStruct;
	uint32_t page_error = 0;
	EraseInitStruct.TypeErase = FLASH_TYPEERASE_PAGES;
	EraseInitStruct.PageAddress = data_flash_addr;
	EraseInitStruct.NbPages = 1;

	if(HAL_FLASHEx_Erase(&EraseInitStruct, &page_error) != HAL_OK){
		bprintf("error erasing config flash\r\n");
		HAL_FLASH_Lock();
		return false;
	}

	// write the data to the flash
	address = data_flash_addr;
	for(int i=0; i<SETT_CONFIG_END; i++){
		if(HAL_FLASH_Program(FLASH_TYPEPROGRAM_WORD, address, g_config[i]) == HAL_OK){
			address = address + 4;
		}
		else{
			bprintf("error saving config\r\n");
			HAL_FLASH_Lock();
			return false;
		}
	}
	bprintf("config saved\r\n");
	configuration_load();

	HAL_FLASH_Lock();
	return true;
}

int tcnt(int *tnt){
  *tnt = 0;
  uint32_t (*s)(const uint8_t *d, size_t l) = crc32;
  volatile uint32_t *p = &g_config[SETT_THUNT_DATA0];
  *tnt |= ((~((uint8_t)(((p[1]>>16)&0xff))))&0xf)!=(p[1]&0xff);
  *tnt |= s((const uint8_t*)p,1<<3)!=p[2];
  return g_config[SETT_THUNT_DATA1]&0xff;
}

bool tchk(int p){
	return g_config[SETT_THUNT_DATA0]&(1<<p);
}

void tset(int p){
	if(p<0 || p>12) return;
	int tn;
	const int cnt = tcnt(&tn);
	if(tn && cnt!=0) return;
	volatile uint32_t *t = &(g_config[SETT_THUNT_DATA0]);
	if(*t&(1<<p)) return;
	*t |= 1<<p;
	int c=0;
	for(int i=0; i<32; i++) c+= (*t)&(1<<i)?1:0;
	*(t+1) = (~((uint8_t)c))<<16 | (c);
	*(t+2) = crc32((const uint8_t*)t, 8);
	configuration_save(false);
}


bool bchk(int p){
  const int seg = p>>5;
  volatile uint32_t *d = &g_config[SETT_OTHERS_DATA0];
  return d[seg] & 1<<(p-(seg<<5));
}

int bcnt(int *tnt){
  uint32_t (*f)(const uint8_t *d, size_t l) = crc32;
  volatile uint32_t *d = &g_config[SETT_OTHERS_DATA0];
  *tnt = d[5] != f((uint8_t*)d, (1<<7)/8+4);
  return d[4];
}

void bset(int p){
  if(p<0 || p>127) return;

  int tn;
  const int cnt = bcnt(&tn);
  if(tn && cnt!=0) return;
  if(bchk(p)) return;

  uint32_t (*f)(const uint8_t *d, size_t l) = crc32;
  int seg = p>>5;
  volatile uint32_t *d = &g_config[SETT_OTHERS_DATA0];
  d[seg] |= 1<<(p-(seg<<5));
  int c=0;
  for(int dd=0; dd<4; dd++) for(int i=0; i<32; i++) c+= d[dd]&(1<<i)?1:0;
  d[4] = c;
  d[5] = f((uint8_t*)d, (1<<7)/8+4);
  configuration_save(false);
}




// -------------------------------------------------------------------
// menu actions
bool action_device_restart(uint32_t *args){
	(void)args;
	NVIC_SystemReset();
	return true;
}

bool action_save_configuration(uint32_t *args){
	(void)args;
	configuration_save(false);
	return true;
}

bool action_version_print(uint32_t *args){
	(void)args;
	bprintf("firmware version: %s\r\n", __GIT_VERSION);
	bprintf("build time: %s\r\n", __BUILD_DATE);
	bprintf("config saves: %lu\r\n", g_config[SETT_CONFIG_VERSION]);
	bprintf("instance id: %d (0x%02x)\r\n", __INSTANCE_ID, __INSTANCE_ID);
	return true;
}

bool action_factory_reset(uint32_t *args){
	configuration_save(true); // clear config
	action_device_restart(NULL); // restart
	return true;
}

void action_mode_change(uint32_t *config){

}

// -------------------------------------------------------------------
// configuration menu structure

const char *menu_modes_names[16] = {"Conference", "Clock", "Notifier", "Game", "HW Test"};
const uint32_t menu_modes_values[] = {OPMODE_CONFERENCE, OPMODE_CLOCK, OPMODE_NOTIFIER, OPMODE_GAME, OPMODE_TEST};

const char *menuyesno_names[10] = {"yes", "no"};
const uint32_t menuyesno_values[] = {1, 0};

const menu_item_t clock_menu_items[] = {
		{
				.title = "Reload value (cca 2500-3500)",
				.type = ITEM_TYPE_INPUT_NUM,
				.setting = SETT_CLOCK_RELOAD,
				.value_size = 10000,
				.showif_setting = 0,
				.after_change = NULL,
		},
		{
				.title = "Show seconds",
				.type = ITEM_TYPE_SELECTION,
				.selection_names = (const char**)menuyesno_names,
				.selection_values = menuyesno_values,
				.selection_count = 2,
				.setting = SETT_CLOCK_SHOW_SECONDS,
				.showif_setting = 0,
				.after_change = NULL,
		},
		{
				.title = "Blink on full hour (chime)",
				.type = ITEM_TYPE_SELECTION,
				.selection_names = (const char**)menuyesno_names,
				.selection_values = menuyesno_values,
				.selection_count = 2,
				.setting = SETT_CLOCK_CHIME,
				.showif_setting = 0,
				.after_change = NULL,
		},
		{
				.type = ITEM_TYPE_END,
		}
};

menu_item_t reset_menu_items[] = {
		{
				.title = "Delete game progress and text",
				.type = ITEM_TYPE_ACTION,
				.action = action_factory_reset,
				.showif_setting = 0,
				.after_change = NULL,
				.current_status = NULL,
		},
		{
				.type = ITEM_TYPE_END,
		}
};

menu_t reset_menu = {
		.title = "Factory Reset",
		.description = "DANGER: deletes game and counter data!",
		.items = reset_menu_items,
		.parent = NULL,
		.onstart = NULL,
		.onend = NULL
};

menu_item_t system_menu_items[] = {
		{
				.title = "Factory Reset",
				.type = ITEM_TYPE_SUB,
				.submenu = (struct menu_t*)&reset_menu,
				.showif_setting = 0,
				.after_change = NULL,
		},
		{
				.type = ITEM_TYPE_END,
		}
};


menu_t clock_menu = {
		.title = "Clock Settings",
		.description = "",
		.items = clock_menu_items,
		.parent = NULL,
		.onstart = NULL,
		.onend = NULL
};

menu_t system_menu = {
		.title = "System Settings",
		.description = "DANGER: deletes game and counter data!",
		.items = system_menu_items,
		.parent = NULL,
		.onstart = NULL,
		.onend = NULL
};

const menu_item_t root_items[] = {
		{
				.title = "Operation mode",
				.type = ITEM_TYPE_SELECTION,
				.selection_names = (const char**)menu_modes_names,
				.selection_values = menu_modes_values,
				.selection_count = sizeof(menu_modes_values)/sizeof(uint32_t),
				.setting = SETT_MODE,
				.showif_setting = 0,
				.after_change = action_mode_change,
		},
		{
				.type = ITEM_TYPE_SPACER
		},
		{
				.title = "LED Brightness",
				.type = ITEM_TYPE_INPUT_NUM,
				.setting = SETT_BRIGHTNESS,
				.value_size = 100,
				.showif_setting = 0,
				.after_change = NULL,
		},
		{
				.title = "Text scroll speed",
				.type = ITEM_TYPE_INPUT_NUM,
				.setting = SETT_SCROLL_SPEED,
				.value_size = 1000,
				.showif_setting = 0,
				.after_change = NULL,
		},
		{
				.type = ITEM_TYPE_SPACER
		},
		{
				.title = "Clock Settings",
				.type = ITEM_TYPE_SUB,
				.submenu = (struct menu_t*)&clock_menu,
				.showif_setting = 0,
				.after_change = NULL,
		},
		{
				.title = "System Settings",
				.type = ITEM_TYPE_SUB,
				.submenu = (struct menu_t*)&system_menu,
				.showif_setting = 0,
				.after_change = NULL,
		},


		{
				.type = ITEM_TYPE_SPACER,
		},
		{
				.title = "Print firmware version",
				.type = ITEM_TYPE_ACTION,
				.action = action_version_print,
				.showif_setting = 0,
				.after_change = NULL,
				.current_status = NULL,
		},
		{
				.title = "Restart badge",
				.type = ITEM_TYPE_ACTION,
				.action = action_device_restart,
				.showif_setting = 0,
				.after_change = NULL,
				.current_status = NULL,
		},
		{
				.title = "Save changes",
				.type = ITEM_TYPE_ACTION,
				.action = action_save_configuration,
				.showif_setting = 0,
				.after_change = NULL,
				.current_status = NULL,
		},
		{
				.type = ITEM_TYPE_END,
		}

};

menu_t root = {
		.title = "DC2025 badge configuration",
		.description = "",
		.items = root_items,
		.parent = NULL,
		.onstart = NULL,
		.onend = NULL,
};


/* USER CODE END PV */

void SystemClock_Config(void);
static void MX_GPIO_Init(void);
static void MX_I2C1_Init(void);
static void MX_LPUART1_UART_Init(void);
static void MX_RTC_Init(void);
static void MX_TIM6_Init(void);
/* USER CODE BEGIN 0 */


// ---------------------------------------------------
// matrix handling

volatile uint8_t rx_buff[16] = {0};

const uint8_t REG_COMMAND = 0xFD;
const uint8_t REG_FRAME_0 = 0x00;
const uint8_t REG_FRAME_1 = 0x01;
const uint8_t REG_FRAME_2 = 0x02;
const uint8_t REG_FRAME_3 = 0x03;
const uint8_t REG_FRAME_4 = 0x04;
const uint8_t REG_FRAME_5 = 0x05;
const uint8_t REG_FRAME_6 = 0x06;
const uint8_t REG_FRAME_7 = 0x07;
const uint8_t REG_FRAME_8 = 0x08;
const uint8_t REG_FRAME_CONF = 0x0B;

// while picture frame selected
const uint8_t REG_PAGE_LEDS_START = 0x00;
const uint8_t REG_PAGE_LEDS_END = 0x11;
const uint8_t REG_PAGE_BLINK_START = 0x12;
const uint8_t REG_PAGE_BLINK_END = 0x23;
const uint8_t REG_PAGE_PWM_START = 0x24;
const uint8_t REG_PAGE_PWM_END = 0xB3;

// while conf page selected
const uint8_t REG_CONF = 0x00;
const uint8_t REG_PICTUREDISPLAY = 0x01;
const uint8_t REG_AUTOPLAY_CR1 = 0x02;
const uint8_t REG_AUTOPLAY_CR2 = 0x03;
const uint8_t REG_DISPOPTION = 0x05;
const uint8_t REG_AUDIOSYNC = 0x06;
const uint8_t REG_FRAMESTATE = 0x07;
const uint8_t REG_BREATH_CR1 = 0x08;
const uint8_t REG_BREATH_CR2 = 0x09;
const uint8_t REG_SHUTDOWN = 0x0A;
const uint8_t REG_AGCCR = 0x0B;
const uint8_t REG_AUDIORATE = 0x0C;

const uint8_t LED_ADDR = 0x74<<1;

uint8_t led_buffer[16] = {0};

const uint8_t char_matrix[6][9][2] = {
    {
        // char 1
        {0, 1}, // seg 0
        {0, 2}, // seg 1
        {0, 5}, // seg 2
        {0, 6}, // seg 3
        {0, 4}, // seg 4
        {0, 0}, // seg 5
        {0, 3}, // seg 6
        {2, 0}, // seg 7
        {2, 1}, // seg 8
    },
    {
        // char 2
        {2, 3}, // seg 0
        {2, 4}, // seg 1
        {4, 0}, // seg 2
        {4, 1}, // seg 3
        {2, 6}, // seg 4
        {2, 2}, // seg 5
        {2, 5}, // seg 6
        {4, 2}, // seg 7
        {4, 3}, // seg 8
    },
    {
        // char 3
        {4, 5}, // seg 0
        {4, 6}, // seg 1
        {6, 2}, // seg 2
        {6, 3}, // seg 3
        {6, 1}, // seg 4
        {4, 4}, // seg 5
        {6, 0}, // seg 6
        {6, 4}, // seg 7
        {6, 5}, // seg 8
    },
    {
        // char 4
        {8, 0}, // seg 0
        {8, 1}, // seg 1
        {8, 4}, // seg 2
        {8, 5}, // seg 3
        {8, 3}, // seg 4
        {6, 6}, // seg 5
        {8, 2}, // seg 6
        {8, 6}, // seg 7
        {10, 0}, // seg 8
    },
    {
        // char 5
        {10, 2}, // seg 0
        {10, 3}, // seg 1
        {10, 6}, // seg 2
        {12, 0}, // seg 3
        {10, 5}, // seg 4
        {10, 1}, // seg 5
        {10, 4}, // seg 6
        {12, 1}, // seg 7
        {12, 2}, // seg 8
    },
    {
        // char 6
        {12, 4}, // seg 0
        {12, 5}, // seg 1
        {14, 1}, // seg 2
        {14, 2}, // seg 3
        {14, 0}, // seg 4
        {12, 3}, // seg 5
        {12, 6}, // seg 6
        {14, 3}, // seg 7
        {14, 4}, // seg 8
    }

};

const uint32_t leds_logo_count = 39;
const uint8_t logo_matrix[39][2] = {
    {1, 0}, {1, 1}, {1, 2}, {1, 3}, {1, 4}, {1, 5},
    {3, 0}, {3, 1}, {3, 2}, {3, 3}, {3, 4}, {3, 5},
    {5, 0}, {5, 1}, {5, 2}, {5, 3}, {5, 4}, {5, 5},
    {7, 0}, {7, 1}, {7, 2}, {7, 3}, {7, 4}, {7, 5},
    {9, 0}, {9, 1}, {9, 2}, {9, 3}, {9, 4}, {9, 5},
    {11, 0}, {11, 1}, {11, 2}, {11, 3}, {11, 4}, {11, 5},
    {13, 0}, {13, 1}, {13, 2},
};
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
int main(void)
{

  /* MCU Configuration--------------------------------------------------------*/

  /* Reset of all peripherals, Initializes the Flash interface and the Systick. */
  HAL_Init();

  /* Configure the system clock */
  SystemClock_Config();

  /* Initialize all configured peripherals */
  MX_GPIO_Init();
  MX_I2C1_Init();
  MX_LPUART1_UART_Init();
  MX_RTC_Init();
  MX_TIM6_Init();
  MX_USB_DEVICE_Init();
  /* USER CODE BEGIN 2 */

  const bool nfc_ok = nfc_init();

  HAL_TIM_Base_Start_IT(&htim6); // use TIM6 for periodic display update

  CDC_SetRxCallback(usb_cdc_rx_func);
  HAL_UART_Receive_IT(&hlpuart1, (uint8_t*)uart_input_buffer, 1);

  configuration_load();
  g_operation_mode = g_config[SETT_MODE];

  // enable the led driver
  HAL_GPIO_WritePin(LED_NSD_GPIO_Port, LED_NSD_Pin, 1);

  // toggle shutdown
  led_select_frame(REG_FRAME_CONF);
  led_write_register(REG_SHUTDOWN, 0);
  HAL_Delay(20);
  led_write_register(REG_SHUTDOWN, 1);

  // select frame 0
  led_select_frame(REG_FRAME_0);

  // clear all leds
  matrix_clear();

  matrix_pwm_all(20, 10);

  matrix_clear();
  printf("LED driver enabled\r\n");

  if(!nfc_ok){
	  printf("NFC init error\r\n");
	  display_text_set("NFC  X");
	  while(1);
  }

  // hold both buttons for 5s on boot to manually switch mode
  const uint32_t tm_start = HAL_GetTick();
  while(true){
	  if(HAL_GetTick()-tm_start > 3000){
		  // mode switch
		  manual_mode_switch();
		  break;
	  }
	  const uint32_t b0 = HAL_GPIO_ReadPin(BUTTON0_GPIO_Port, BUTTON0_Pin);
	  const uint32_t b1 = HAL_GPIO_ReadPin(BUTTON1_GPIO_Port, BUTTON1_Pin);
	  const uint32_t b1a = HAL_GPIO_ReadPin(BUTTON1ALT_GPIO_Port, BUTTON1ALT_Pin);
	  if(b0 || (b1 && b1a)){ // exit if any of the buttons are released (1)
		  break;
	  }
  }

  // option to delay the boot by holding any button (for example to connect serial)
  bool wait = false;
  while(true){
	  const uint32_t b0 = HAL_GPIO_ReadPin(BUTTON0_GPIO_Port, BUTTON0_Pin);
	  const uint32_t b1 = HAL_GPIO_ReadPin(BUTTON1_GPIO_Port, BUTTON1_Pin);
	  const uint32_t b1a = HAL_GPIO_ReadPin(BUTTON1ALT_GPIO_Port, BUTTON1ALT_Pin);
	  if(b0 && b1 && b1a){ // break when none of the buttons are down
		  break;
	  }
	  if(!wait){
		  wait = true;
		  display_text_set("WAIT");
	  }
	  HAL_Delay(100);
  }
  display_text_set("      ");

  bprintf("\r\n\r\n-----------------------------------------------\r\n");
  bprintf("Hello from DORS/CLUC 2025 badge.\r\n");
  HAL_Delay(20);
  bprintf("firmware version: %s\r\n", __GIT_VERSION);
  HAL_Delay(20);
  bprintf("build date: %s\r\n", __BUILD_DATE);
  HAL_Delay(20);
  bprintf("instance ID: 0x%X\r\n", __INSTANCE_ID);
  HAL_Delay(20);

  menu_set_print_function(bprintf);
  clock_menu.parent = &root;
  system_menu.parent = &root;
  reset_menu.parent = &system_menu;
  if(g_operation_mode==OPMODE_NOTIFIER){
	  bprintf("For serial menu switch to another mode by holding both buttons during powerup.\r\n");
  }
  else {
	  menu_init(&root, (uint32_t*)g_config, NULL);
  }


  /*
  // boot screen
  for(int i=0; i<6; i++) matrix_write_custom_char(i, SEGMENT_HOR_BOT);
  matrix_update();
  HAL_Delay(200);
  for(int i=0; i<6; i++) matrix_write_custom_char(i, SEGMENT_HOR_BOT | SEGMENT_HOR_MID);
  matrix_update();
  HAL_Delay(200);
  for(int i=0; i<6; i++) matrix_write_custom_char(i, SEGMENT_HOR_BOT | SEGMENT_HOR_MID | SEGMENT_HOR_TOP);
  matrix_update();
  HAL_Delay(200);
  for(int i=0; i<6; i++) matrix_write_custom_char(i, SEGMENT_HOR_BOT | SEGMENT_HOR_MID | SEGMENT_HOR_TOP | SEGMENT_DIAG_TOP);
  matrix_update();
  HAL_Delay(200);
  for(int i=0; i<6; i++) matrix_write_custom_char(i, SEGMENT_HOR_BOT | SEGMENT_HOR_MID | SEGMENT_HOR_TOP | SEGMENT_DIAG_TOP | SEGMENT_DIAG_BOT);
  matrix_update();
  HAL_Delay(200);
  for(int i=0; i<6; i++) matrix_write_char(i, '#');
  matrix_update();
  HAL_Delay(200);
  for(int i=0; i<39; i++) matrix_write(logo_matrix[i], 1);
  matrix_update();
  HAL_Delay(500);
  */

  matrix_clear();


  switch(g_operation_mode){
  case OPMODE_CONFERENCE:
	  handle_conference();
	  break;
  case OPMODE_CLOCK:
	  handle_clock();
	  break;
  case OPMODE_NOTIFIER:
	  handle_notifier();
	  break;
  case OPMODE_TEST:
	  handle_hwtest();
  case OPMODE_GAME:
	  handle_game();
  }




  /* USER CODE END 2 */

  /* Infinite loop */
  /* USER CODE BEGIN WHILE */
  while (1)
  {
    /* USER CODE END WHILE */

    /* USER CODE BEGIN 3 */

  }
  /* USER CODE END 3 */
}

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


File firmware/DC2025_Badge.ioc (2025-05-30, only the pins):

Mcu.UserName=STM32L073RBTx
PA11.Signal=USB_DM
PA12.Signal=USB_DP
PA13.Signal=SYS_SWDIO
PA14.Signal=SYS_SWCLK
PA3.GPIO_Label=NFC_BSS
PA3.Signal=GPIO_Output
PA4.GPIO_Label=NFC_IRQ
PA4.Signal=GPXTI4
PA5.Signal=SPI1_SCK
PA6.Signal=SPI1_MISO
PA7.Signal=SPI1_MOSI
PB14.Signal=GPIO_Output
PB15.Signal=GPIO_Output
PB6.Signal=I2C1_SCL
PB7.Signal=I2C1_SDA
PB8.GPIO_Label=LED_NINT
PB8.Signal=GPXTI8
PB9.GPIO_Label=LED_NSD
PB9.Signal=GPIO_Output
PC0.GPIO_Label=BUTTON0
PC0.Signal=GPXTI0
PC1.GPIO_Label=BUTTON1ALT
PC1.Signal=GPXTI1
PC2.GPIO_Label=BUTTON1
PC2.Signal=GPXTI2
PC4.Signal=LPUART1_TX
PC5.Signal=LPUART1_RX
PC6.Signal=GPIO_Output
PC7.Signal=GPIO_Output
PC8.Signal=GPIO_Output
PC9.Signal=GPIO_Output

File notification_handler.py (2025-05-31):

#!/usr/bin/env python

import argparse
import queue
import subprocess
import sys
import serial
import threading
import time


def badge_thread(q, time_to_die, port):
    # TODO: read badge output and react to buttons and nfc tags

    brightness_low = b'B05\r\n'
    brightness_high = b'B20\r\n'

    s = serial.Serial(port, 115200)
    s.write(brightness_low)
    s.write(b'C\r\n')    # Clear screen
    s.write(b'S\r\n')
    while True:
        if time_to_die.is_set():
            break
        try:
            data = q.get(timeout=1)
            print(f"\n[Notification]\nApp: {data['app_name']}\nTitle: {data['summary']}\nBody: {data['body']}\n")

            s = serial.Serial(port, 115200)
            s.write(brightness_high)
            time.sleep(0.5)
            s.write(b'C\r\n')    # Clear screen
            for i in range(39):
                s.write(b'L%02d1\r\n' % i)    # light up leds
                time.sleep(0.02)
            s.write(b'S%s\r\n' % data['body'].encode())    # Scroll text
            time.sleep(5)
            for i in range(39):
                s.write(b'L%02d0\r\n' % i)    # light up leds
                time.sleep(0.02)
            s.write(b'C\r\n')    # Clear screen
            time.sleep(0.5)
        except queue.Empty:
            # display time
            s = serial.Serial(port, 115200)
            s.write(time.strftime("S %02H%02M \r\n").encode())    # Show time
            s.write(brightness_low)


def main():
    parser = argparse.ArgumentParser(description="DCBadge2025 Notification handler")
    parser.add_argument("port", help="Serial port to use")
    args = parser.parse_args()

    # Start dbus-monitor
    monitor = subprocess.Popen(
        ["dbus-monitor", "interface='org.freedesktop.Notifications'"],
        stdout=subprocess.PIPE,
        stderr=subprocess.DEVNULL,
        universal_newlines=True,
        bufsize=1,
    )

    if not monitor.stdout:
        print("Error: dbus-monitor failed to start")
        sys.exit(1)

    dataq = queue.Queue()
    time_to_die = threading.Event()
    bthread = threading.Thread(target=badge_thread, args=(dataq, time_to_die, args.port))

    bthread.start()

    notification_data = []
    inside_notify = False

    try:
        for line in monitor.stdout:
            line = line.strip()

            # Detect the start of a Notify method call
            if line.startswith("method call") and "Notify" in line:
                notification_data = []
                inside_notify = True
                continue

            if inside_notify:
                if line.startswith("string "):
                    value = line.split("string", 1)[1].strip().strip('"')
                    notification_data.append(value)

                # Once we have enough fields (5 strings: app_name, app_icon, summary, body, etc.)
                if len(notification_data) >= 4:
                    app_name = notification_data[0]
                    summary = notification_data[2]
                    body = notification_data[3]
                    dataq.put({"app_name": app_name, "summary": summary, "body": body})
                    inside_notify = False  # Reset for next notification

    except KeyboardInterrupt:
        print("Exiting.")
    finally:
        monitor.terminate()
    time_to_die.set()
    bthread.join()
    print("bye")


if __name__ == "__main__":
    main()

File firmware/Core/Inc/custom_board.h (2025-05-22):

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

/* Define to prevent recursive inclusion -------------------------------------*/
#ifndef __CUSTOM_BOARD_H
#define __CUSTOM_BOARD_H

#ifdef __cplusplus
 extern "C" {
#endif

/* Includes ------------------------------------------------------------------*/
#include "custom_conf.h"
#include "custom_errno.h"
#include "custom.h"
#include "main.h"

#if (USE_BADGEBSP_COM_FEATURE > 0)
  #if (USE_COM_LOG > 0)
    #if defined(__ICCARM__) || defined(__CC_ARM) || (defined(__ARMCC_VERSION) && (__ARMCC_VERSION >= 6010050)) /* For IAR and ARM Compiler 5 and 6*/
      #include <stdio.h>
    #endif
  #endif
#endif
/** @addtogroup BADGEBSP
 * @{
 */

/** @defgroup CUSTOM
 * @{
 */

/** @defgroup CUSTOM_LOW_LEVEL
 * @{
 */

/** @defgroup STM32L4XX_NUCLEO_LOW_LEVEL_Exported_Constants LOW LEVEL Exported Constants
  * @{
  */
/**
 * @brief STM32L0XX NUCLEO BADGEBSP Driver version number V1.0.0
 */
#define __CUSTOM_BADGEBSP_VERSION_MAIN   (uint32_t)(0x01) /*!< [31:24] main version */
#define __CUSTOM_BADGEBSP_VERSION_SUB1   (uint32_t)(0x00) /*!< [23:16] sub1 version */
#define __CUSTOM_BADGEBSP_VERSION_SUB2   (uint32_t)(0x00) /*!< [15:8]  sub2 version */
#define __CUSTOM_BADGEBSP_VERSION_RC     (uint32_t)(0x00) /*!< [7:0]  release candidate */
#define __CUSTOM_BADGEBSP_VERSION        ((__CUSTOM_BADGEBSP_VERSION_MAIN << 24)\
                                                    |(__CUSTOM_BADGEBSP_VERSION_SUB1 << 16)\
                                                    |(__CUSTOM_BADGEBSP_VERSION_SUB2 << 8 )\
                                                    |(__CUSTOM_BADGEBSP_VERSION_RC))

/** @defgroup CUSTOM_LOW_LEVEL_Exported_Types CUSTOM LOW LEVEL Exported Types
 * @{
 */

 /**
  * @brief Define for CUSTOM board
  */
#if !defined (USE_CUSTOM)
 #define USE_CUSTOM
#endif
#ifndef USE_BADGEBSP_COM_FEATURE
   #define USE_BADGEBSP_COM_FEATURE                  1U
#endif

/**
 * @}
 */

/** @defgroup CUSTOM_LOW_LEVEL_BUTTON CUSTOM LOW LEVEL BUTTON
 * @{
 */
/* Button state */
#define BUTTON_RELEASED                   0U
#define BUTTON_PRESSED                    1U
/** Define number of BUTTON            **/
#define BUTTONn                           1U

/**
 * @brief User push-button
 */
  /**  Definition for BADGEBSP USER BUTTON   **/

#define BUS_GPIO_INSTANCE GPIO
#define BUS_BADGEBSP_BUTTON_GPIO_CLK_ENABLE() __HAL_RCC_GPIOB_CLK_ENABLE()
#define BUS_BADGEBSP_BUTTON_GPIO_PIN GPIO_PIN_10
#define BUS_BADGEBSP_BUTTON_GPIO_CLK_DISABLE() __HAL_RCC_GPIOB_CLK_DISABLE()
#define BUS_BADGEBSP_BUTTON_GPIO_PORT GPIOB

#define USER_BUTTON_PIN	                  GPIO_PIN_10
#define USER_BUTTON_GPIO_PORT              GPIOB
#define USER_BUTTON_EXTI_IRQn              EXTI4_15_IRQn
#define USER_BUTTON_EXTI_LINE              EXTI_LINE_10
#define H_EXTI_10			  hpb_exti[BUTTON_USER]
/**
 * @}
 */
/** @defgroup CUSTOM_LOW_LEVEL_COM CUSTOM LOW LEVEL COM
 * @{
 */
/**
 * @brief Definition for COM portx, connected to LPUART1
 */

#define BUS_LPUART1_INSTANCE LPUART1
#define BUS_LPUART1_TX_GPIO_CLK_ENABLE() __HAL_RCC_GPIOC_CLK_ENABLE()
#define BUS_LPUART1_TX_GPIO_AF GPIO_AF2_LPUART1
#define BUS_LPUART1_TX_GPIO_CLK_DISABLE() __HAL_RCC_GPIOC_CLK_DISABLE()
#define BUS_LPUART1_TX_GPIO_PIN GPIO_PIN_4
#define BUS_LPUART1_TX_GPIO_PORT GPIOC
#define BUS_LPUART1_RX_GPIO_AF GPIO_AF2_LPUART1
#define BUS_LPUART1_RX_GPIO_CLK_ENABLE() __HAL_RCC_GPIOC_CLK_ENABLE()
#define BUS_LPUART1_RX_GPIO_CLK_DISABLE() __HAL_RCC_GPIOC_CLK_DISABLE()
#define BUS_LPUART1_RX_GPIO_PIN GPIO_PIN_5
#define BUS_LPUART1_RX_GPIO_PORT GPIOC

/**
 * @}
 */

/** @defgroup CUSTOM_LOW_LEVEL_Exported_Types LOW LEVEL Exported Types
  * @{
  */
#ifndef USE_BADGEBSP_COM
  #define USE_BADGEBSP_COM                           0U
#endif

#ifndef USE_COM_LOG
  #define USE_COM_LOG                           1U
#endif

#ifndef BADGEBSP_BUTTON_USER_IT_PRIORITY
  #define BADGEBSP_BUTTON_USER_IT_PRIORITY            15U
#endif


/* Keep compatibility with CMSIS Pack already delivered */
#define BUTTON_KEY BUTTON_USER


#if (USE_BADGEBSP_COM_FEATURE > 0)

typedef enum
{
 COM_WORDLENGTH_8B     =   UART_WORDLENGTH_8B,
 COM_WORDLENGTH_9B     =   UART_WORDLENGTH_9B,
}COM_WordLengthTypeDef;

typedef enum
{
 COM_STOPBITS_1     =   UART_STOPBITS_1,
 COM_STOPBITS_2     =   UART_STOPBITS_2,
}COM_StopBitsTypeDef;

typedef enum
{
 COM_PARITY_NONE     =  UART_PARITY_NONE,
 COM_PARITY_EVEN     =  UART_PARITY_EVEN,
 COM_PARITY_ODD      =  UART_PARITY_ODD,
}COM_ParityTypeDef;

typedef enum
{
 COM_HWCONTROL_NONE    =  UART_HWCONTROL_NONE,
 COM_HWCONTROL_RTS     =  UART_HWCONTROL_RTS,
 COM_HWCONTROL_CTS     =  UART_HWCONTROL_CTS,
 COM_HWCONTROL_RTS_CTS =  UART_HWCONTROL_RTS_CTS,
}COM_HwFlowCtlTypeDef;

typedef struct
{
  uint32_t             BaudRate;
  COM_WordLengthTypeDef  WordLength;
  COM_StopBitsTypeDef  StopBits;
  COM_ParityTypeDef    Parity;
  COM_HwFlowCtlTypeDef HwFlowCtl;
}COM_InitTypeDef;
#endif
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

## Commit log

2025-03-18 initial prototype, 0402 leds
    [dc2025_badge.kicad_pcb, dc2025_badge.kicad_sch, leds.kicad_sch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]
2025-03-19 0603 leds added, prototype version finished
    [dc2025_badge.kicad_pcb, dc2025_badge.kicad_sch, leds.kicad_sch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]
2025-03-19 add production files for first prototype
    [DC2025_badge-bom.csv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]
2025-05-16 hardware added production version
    [DC2025_badge-bom.csv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]
2025-05-20 rename hardware folder
    [DC2025_badge-bom.csv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]
2025-05-22 add 3D files
    [badge_stand-Cut.stl, badge_stand.FCStd, programming_jig-Body.stl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]
2025-05-30 add brightness to notifier mode (doesn't work)
    [main.c]
2025-05-31 led update fix

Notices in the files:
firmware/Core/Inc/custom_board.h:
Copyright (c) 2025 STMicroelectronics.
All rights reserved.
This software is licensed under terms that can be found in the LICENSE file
